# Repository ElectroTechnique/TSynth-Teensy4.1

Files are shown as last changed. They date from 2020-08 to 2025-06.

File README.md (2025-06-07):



# Teensy 4.1 based synthesizer using PJRC Audio Board and Audio Lib

Website: [electrotechnique.cc](https://electrotechnique.cc)

Front panel and Main PCB files are now available if you wan to get your own from a PCB facility like JLCPCB.

~~The pcb and front panel to build TSynth are available from [Tindie](https://www.tindie.com/products/electrotechnique/tsynth-teensy-based-diy-programmable-poly-synth/) with SMD 4067 multiplexers, 6N137 opto-isolator, capacitors and resistors fitted.~~ 

The entire cost of parts to build TSynth will be around $99 if you buy components from the cheaper suppliers and the build time around two hours to solder.
Plans for a 3D printed/laser cut enclosure are also available.

Questions: info@electrotechnique.cc

# Preset Patches
Format your SD card using [the SD Association formatter](https://www.sdcard.org/downloads/formatter/). Copy all the presets straight on to the card with no other files or folders.

# Instructions

The source code **requires** the latest Teensyduino from [PJRC](https://pjrc.com) to compile. You also need CircularBuffer from Agileware and Adafruit_GFX, which are available in the Arduino Library Manager.

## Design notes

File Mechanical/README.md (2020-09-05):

- Electrical schematic
- 3D models - End cheeks, side panel columns, display standoff, encoder knob (D-shape shaft)

    EncoderKnobEC12_6mm is for 6mm splined encoder shafts
    
    EncoderKnobEC12_D_shape is for 6mm D-shaped encoder shafts

- Laser cutter plans - Sides and base

    T4_1_LaserCutCase3_5Jk.svg - Is for PCBs with 3.5mm headphone sockets
  
    T4_1_LaserCutCase6_35Jk.svg - Is for PCBs with 1/4" / 6.35mm headphone sockets
  
- BOM Excel file for ordering from Mouser

Fusion 360 models. These have internal dimensions for slots that are slightly bigger, to account for shrinkage of PLA plastic:
- [End Cheeks](https://a360.co/3azEESA)
- [Side Panel Column](https://a360.co/34T8akU)

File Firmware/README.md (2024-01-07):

Get the firmware file from [RELEASES](https://github.com/ElectroTechnique/TSynth-Teensy4.1/releases) on the right-hand side of the main page.

Use [TyUploader](https://github.com/Koromix/tytools/releases/tag/v0.9.9) instead of TeensyDuino if you are tired of trying to press the Boot button on the T4.1

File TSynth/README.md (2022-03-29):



# Teensy 4.1 based synthesizer using PJRC Audio Board and Audio Lib

Website: [electrotechnique.cc](https://electrotechnique.cc)

The pcb and front panel to build TSynth are available from [Tindie](https://www.tindie.com/products/electrotechnique/tsynth-teensy-based-diy-programmable-poly-synth/) with SMD 4067 multiplexers, 6N137 opto-isolator, capacitors and resistors fitted. The entire cost of parts to build TSynth will be around $99 if you buy components from the cheaper suppliers and the build time around two hours to solder. Plans for a 3D printed/laser cut enclosure are also available.
Questions: info@electrotechnique.cc

# Preset Patches
Format your SD card using [the SD Association formatter](https://www.sdcard.org/downloads/formatter/). Copy all the presets straight on to the card with no other files or folders.

# Instructions

The source code **requires** at least Teensyduino 1.54 from [PJRC](https://pjrc.com) to compile. You also need CircularBuffer from Agileware and Adafruit_GFX, which are available in the Arduino Library Manager. **NOTE** if using Teensyduino 1.55, you'll need to [remove a line from TeensyThreads.cpp](https://forum.pjrc.com/threads/68192-Teensyduino-1-55-Released)

See this thread if you get an error concerning utils/debug.h:  [https://forum.pjrc.com/threads/68192-Teensyduino-1-55-Released?highlight=utils%2Fdebug.h}(https://forum.pjrc.com/threads/68192-Teensyduino-1-55-Released?highlight=utils%2Fdebug.h)

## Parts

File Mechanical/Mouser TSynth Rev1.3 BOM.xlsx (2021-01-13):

Mouser # | Mfr. # | Manufacturer | Description | Order Qty. | Datasheet URL | Quoted Part Number | Order Quantity | Order Price | Min\Mult Order Qty
474-DEV-16771 | DEV-16771 | SparkFun Electronics | Development Boards & Kits - ARM Teensy 4.1 | 1 |  | 474-DEV-16771 | 1 | $29.38 | 1\1
485-4384 | 485-4384 | SparkFun Electronics | Audio IC Development Tools Teensy Audio Adaptor Board Rev D | 1 |  | 485-4384 | 1 | $19.94 | 1\1
652-PTV09A-4025UB103 | PTV09A-4025U-B103 | Bourns | Potentiometers 10K LINEAR 20% | 33 | https://www.mouser.com/datasheet/2/54/ptv09-777818.pdf | 652-PTV09A-4025UB103 | 33 | $0.672 | 1\1
653-B3F-4055 | B3F-4055 | Omron | Tactile Switches 12x12mm Std Ht .3 High-force 260g | 7 | https://www.mouser.com/datasheet/2/307/en-b3f-13826.pdf | 653-B3F-4055 | 7 | $0.44 | 1\1
642-AKTS22K | AKTSC22K | Apem | Switch Bezels / Switch Caps ROUND BLACK CAP | 7 | https://www.mouser.com/catalog/additional/Apem_6420_RoHS_Certificate.pdf | 642-AKTS22K | 7 | $0.23 | 1\1
859-LTL-4251NLC | LTL-4251NLC | Lite-On | Standard LEDs - Through Hole Yellow | 4 | https://www.mouser.com/catalog/additional/Lite_On_5938_RoHS_Certificate.pdf | 859-LTL-4251NLC | 4 | $0.14 | 1\1
652-PEC11R-4215K-S24 | PEC11R-4215K-S0024 | Bourns | Encoders 15mm SHAFT w/SWITCH | 1 | https://www.mouser.com/datasheet/2/54/PEC11R-777457.pdf | 652-PEC11R-4215K-S24 | 1 | $1.63 | 1\1
530-SS-52100-001 | SS-52100-001 | Bel | USB Connectors USB 2.0 R Angle Recpt Type A solder | 1 | https://belfuse.com/resources/datasheets/stewartconnector/ds-stw-usb-2.0-and-3.0-connectors.pdf | 530-SS-52100-001 | 1 | $0.43 | 1\1
530-SS-52300-001 | SS-52300-001 | Bel | USB Connectors USB 2.0 RA Receptacle Type B | 1 | https://belfuse.com/resources/datasheets/stewartconnector/ds-stw-usb-2.0-type-b-connectors.pdf | 530-SS-52300-001 | 1 | $0.98 | 1\1
161-3507-E | 161-3507-E | Kobiconn | Phone Connectors PHONE 3.5MM STEREO | 1 | https://www.mouser.com/datasheet/2/209/KC-301159-1171664.pdf | 161-3507-E | 1 | $0.96 | 1\1
806-KCDX-5S-N | KCDX-5S-N | Kycon | Circular DIN Connectors 5P R/A PCB NON SHLD 10mm CIRC DIN RECPT | 2 | https://www.mouser.com/datasheet/2/222/KCDX-334811.pdf | 806-KCDX-5S-N | 2 | $0.86 | 1\1
568-NYS216G | NYS216G | REAN / Neutrik | Phone Connectors 1/4" STEREO JACK .322" GOLD REAN | 1 | http://www.rean-connectors.com/en/products/1/4-jacks/nys216g | 568-NYS216G | 1 | $0.98 | 1\1
855-R30-1002202 | R30-1002202 | Harwin | Standoffs & Spacers M3 x 22mm THREAD HEX BRASS 5mm A/F | 7 | https://kr.mouser.com/datasheet/2/181/R30-100-1220592.pdf | 855-R30-1002202 | 7 | $0.55 | 1\1
855-R30-3000802 | R30-3000802 | Harwin | Standoffs & Spacers M3 x 8mm HEX 5mm A/F 6mm ML/FML NICKEL | 7 | https://kr.mouser.com/datasheet/2/181/R30-300-1136135.pdf | 855-R30-3000802 | 7 | $0.58 | 1\1
5164-1227-L | 1227-L | Davies Molding | Knobs & Dials S/T Control Knob 6mm Interference Fit | 34 | https://kr.mouser.com/datasheet/2/102/1227-L-1287203.pdf | 5164-1227-L | 34 | $0.91 | 1\1

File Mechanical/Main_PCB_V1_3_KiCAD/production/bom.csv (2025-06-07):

Designator | Footprint | Quantity | Value | LCSC Part #
C1, C10, C11, C12, C13, C14, C15, C16, C17, C18, C19, C2, C20, C21, C22, C23, C24, C25, C26, C27, C28, C29, C3, C30, C31, C32, C33, C34, C35, C36, C37, C4, C5, C6, C7, C8, C9 | 0805 | 37 | 0.1uF
D1 | LED_D3.0mm | 1 | Osc FX LED
D2 | LED_D3.0mm | 1 | Unison LED
D3 | LED_D3.0mm | 1 | Tempo LED
D4 | LED_D3.0mm | 1 | Retrig LED
D5 | D_SOD-323F | 1 | 1N4148WS
ENC1 | RotaryEncoder_Alps_EC11E-Switch_Vertical_H20mm | 1 | Recall
G1, G2 | TSynth PCB Logo 41mm | 2 | Logo
J1 | Jack_3.5mm_Ledino_KB3SPRS_Horizontal | 1 | 3.5mm Jack
J2 | PinHeader_1x03_P2.54mm_Vertical | 1 | To Audio Board
J3 | USB_A_Stewart_SS-52100-001_Horizontal | 1 | USB Host
J4 | USB_B_OST_USB-B1HSxx_Horizontal | 1 | USB Client
J5 | Jack_6.35mm_Neutrik_NMJ6HFD2_Horizontal | 1 | 1/4" Jack
J6 | PinHeader_1x08_P2.54mm_Vertical | 1 | SPI Display
J7 | MIDI_DIN5 | 1 | MIDI In
J8 | MIDI_DIN5 | 1 | MIDI Out/Thru
R10 | 0805 | 1 | 10R
R11 | 0805 | 1 | 33R
R12 | 0805 | 1 | 100R
R3, R4, R6, R8 | 0805 | 4 | 1k5
R7 | 0805 | 1 | 220R
R9 | 0805 | 1 | 4k7
RV1 | Potentiometer_Bourns_PTV09A-1_Single_Vertical | 1 | Noise
RV10 | Potentiometer_Bourns_PTV09A-1_Single_Vertical | 1 | PWM Rate
RV11 | Potentiometer_Bourns_PTV09A-1_Single_Vertical | 1 | Osc2 Pitch
RV12 | Potentiometer_Bourns_PTV09A-1_Single_Vertical | 1 | Osc2 Waveform
RV13 | Potentiometer_Bourns_PTV09A-1_Single_Vertical | 1 | Osc2 PWM Amt
RV14 | Potentiometer_Bourns_PTV09A-1_Single_Vertical | 1 | Osc1 Pitch
RV15 | Potentiometer_Bourns_PTV09A-1_Single_Vertical | 1 | Osc1 Waveform
RV16 | Potentiometer_Bourns_PTV09A-1_Single_Vertical | 1 | Osc1 PWM Amt
RV17 | Potentiometer_Bourns_PTV09A-1_Single_Vertical | 1 | Release Amp
RV18 | Potentiometer_Bourns_PTV09A-1_Single_Vertical | 1 | Sustain Amp
RV19 | Potentiometer_Bourns_PTV09A-1_Single_Vertical | 1 | Decay Amp
RV2 | Potentiometer_Bourns_PTV09A-1_Single_Vertical | 1 | Pitch LFO Rate
RV20 | Potentiometer_Bourns_PTV09A-1_Single_Vertical | 1 | Attack Amp
RV21 | Potentiometer_Bourns_PTV09A-1_Single_Vertical | 1 | Filter LFO Amt
RV22 | Potentiometer_Bourns_PTV09A-1_Single_Vertical | 1 | FX Mix
RV23 | Potentiometer_Bourns_PTV09A-1_Single_Vertical | 1 | FX Amt
RV24 | Potentiometer_Bourns_PTV09A-1_Single_Vertical | 1 | Glide
RV25 | Potentiometer_Bourns_PTV09A-1_Single_Vertical | 1 | Filter LFO Wave
RV26 | Potentiometer_Bourns_PTV09A-1_Single_Vertical | 1 | Filter LFO Rate
RV27 | Potentiometer_Bourns_PTV09A-1_Single_Vertical | 1 | Cutoff
RV28 | Potentiometer_Bourns_PTV09A-1_Single_Vertical | 1 | Resonance
RV29 | Potentiometer_Bourns_PTV09A-1_Single_Vertical | 1 | Filter Type
RV3 | Potentiometer_Bourns_PTV09A-1_Single_Vertical | 1 | Pitch LFO Wave
RV30 | Potentiometer_Bourns_PTV09A-1_Single_Vertical | 1 | Sustain Filter
RV31 | Potentiometer_Bourns_PTV09A-1_Single_Vertical | 1 | Release Filter
RV32 | Potentiometer_Bourns_PTV09A-1_Single_Vertical | 1 | Filter Env Amt
RV33 | Potentiometer_Bourns_PTV09A-1_Single_Vertical | 1 | Volume
RV4 | Potentiometer_Bourns_PTV09A-1_Single_Vertical | 1 | Pitch LFO Amt
RV5 | Potentiometer_Bourns_PTV09A-1_Single_Vertical | 1 | Detune
RV6 | Potentiometer_Bourns_PTV09A-1_Single_Vertical | 1 | Osc Mix
RV7 | Potentiometer_Bourns_PTV09A-1_Single_Vertical | 1 | Attack Filter
RV8 | Potentiometer_Bourns_PTV09A-1_Single_Vertical | 1 | Decay Filter
RV9 | Potentiometer_Bourns_PTV09A-1_Single_Vertical | 1 | Pitch Env Mod
SW1 | SW_PUSH-12mm | 1 | Osc FX
SW2 | SW_PUSH-12mm | 1 | Unison
SW3 | SW_PUSH-12mm | 1 | Tempo
SW4 | SW_PUSH-12mm | 1 | Retrig
SW5 | SW_PUSH-12mm | 1 | Settings
SW6 | SW_PUSH-12mm | 1 | Save
SW7 | SW_PUSH-12mm | 1 | Back
U1 | Teensy41 | 1 | Teensy4.1
U2, U3 | SOIC-24W_7.5x15.4mm_P1.27mm | 2 | CD74HC4067M
U4 | SMDIP-8_W9.53mm | 1 | 6N137
U5 | SOIC-14_3.9x8.7mm_P1.27mm | 1 | 74HC04

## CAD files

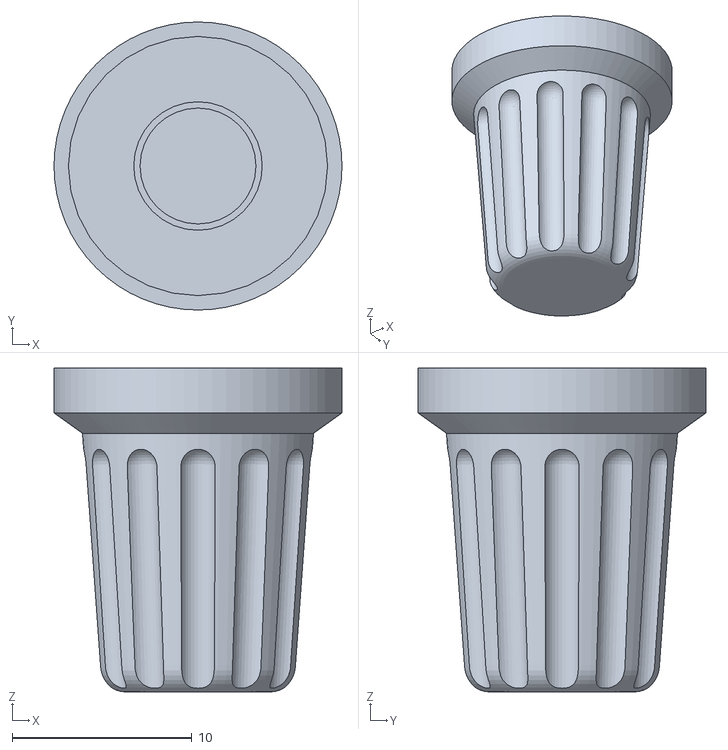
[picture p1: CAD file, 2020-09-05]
Mechanical/EncoderKnobEC12_6mm.stl
16.0 x 16.0 x 18.0

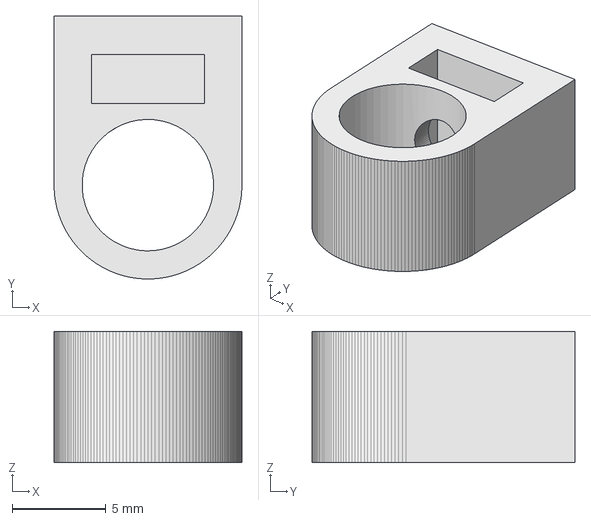
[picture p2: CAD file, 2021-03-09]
Variants/Mechanical/SidePanel_Column_LargerHole.FCStd
10.0 x 14.0 x 7.00 mm

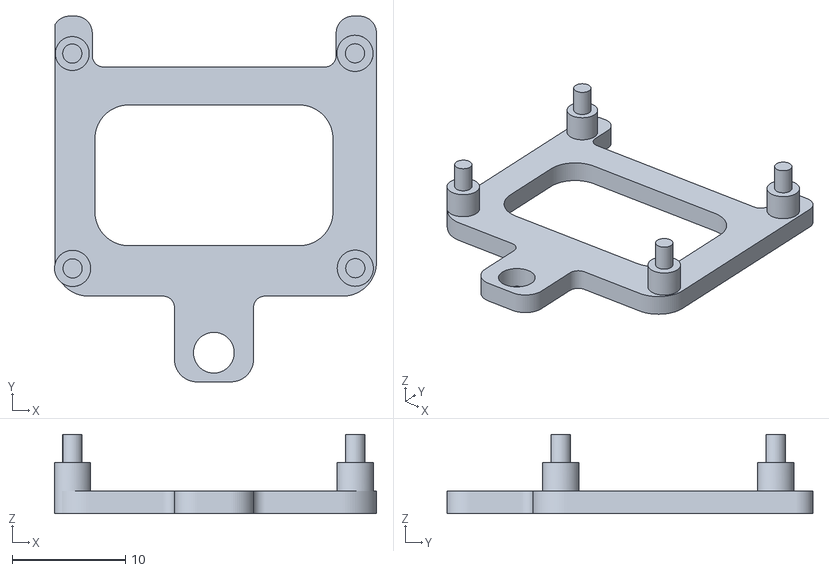
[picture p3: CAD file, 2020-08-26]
Mechanical/0_96_Display_Standoff.stl
28.5 x 32.3 x 7.00

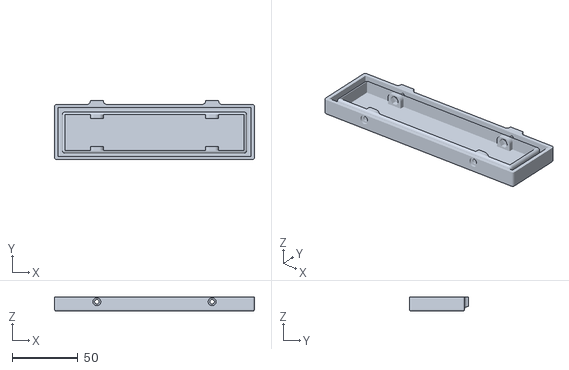
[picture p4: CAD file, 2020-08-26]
Mechanical/EndCheek.stl
152.5 x 45.1 x 11.0

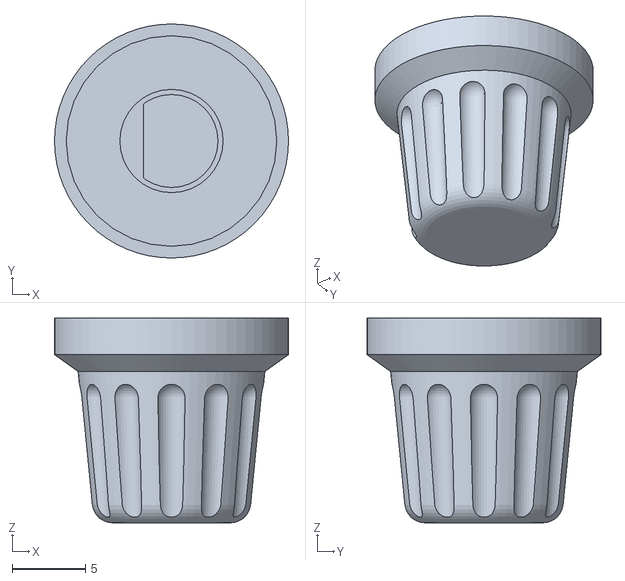
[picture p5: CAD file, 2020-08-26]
Mechanical/EncoderKnobEC12_D_shape.stl
16.0 x 16.0 x 14.0

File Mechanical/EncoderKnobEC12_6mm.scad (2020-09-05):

module pill(_height, _radius){
union() {
translate([0,0,0]) sphere(r=_radius, $fn=32);
translate([0,0,0]) cylinder(r=_radius,h=_height, $fn=32);
translate([0,0,_height]) sphere(r=_radius, $fn=32);
}
}


module base1(_base_height,_base_radius,_knob_radius) {
union() {
cylinder(r=_base_radius, h=_base_height, $fn=64);
translate([0,0,_base_height]) cylinder(r1=_base_radius, r2=_knob_radius, h=5, $fn=64);
}
}
module base2(_base_height,_base_radius,_ring_radius) {
union() {
cylinder(r1=_base_radius+1, r2=_base_radius, h=_base_height, $fn=64);
translate([0,0,_base_height]) rotate_extrude(convexity = 10, $fn=64)
translate([_base_radius-_ring_radius, 0, 0])
circle(r = _ring_radius, $fn=32);
translate([0,0,_base_height]) cylinder(r=_base_radius-_ring_radius, h=_ring_radius, $fn=64);
}
}

base_height=2.5;
base_radius=8;

knob_height=14;//16
knob_radius=5.5;

shaft_radius=3.22;//3.18;//3.1
nut_radius=7.2;
nut_height=2.7;
shaft_height=8.8;//16
shaft_height_total=13;//18


rotate([0,180,0]) {
    difference(){
union(){
base1(base_height, base_radius, 1);

translate([0,0,base_height]) {
difference() {
base2(knob_height, knob_radius, 1.5);
for (i=[0:30:360]) {
   rotate([0,0,i]) translate([knob_radius+1,0,3]) rotate([0,-3.5,0]) pill(knob_height+1, 1);
}
}
}
}
union() {
cylinder(r=nut_radius, h=nut_height,$fn=32);
difference() {
    union() {
cylinder(r=shaft_radius, h=shaft_height_total,$fn=32);

cylinder(r=shaft_radius+0.35, h=shaft_height_total-shaft_height,$fn=32);
    }
//#translate([1.9,-shaft_radius,shaft_height_total-shaft_height]) //cube([2*shaft_radius,2*shaft_radius,shaft_height]);
}
}
}

}

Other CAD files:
Mechanical/Side_Panel_Column.stl
Mechanical/EncoderKnobEC12_D_shape.scad
Variants/Mechanical/SidePanel_Column_LargerHole.stl

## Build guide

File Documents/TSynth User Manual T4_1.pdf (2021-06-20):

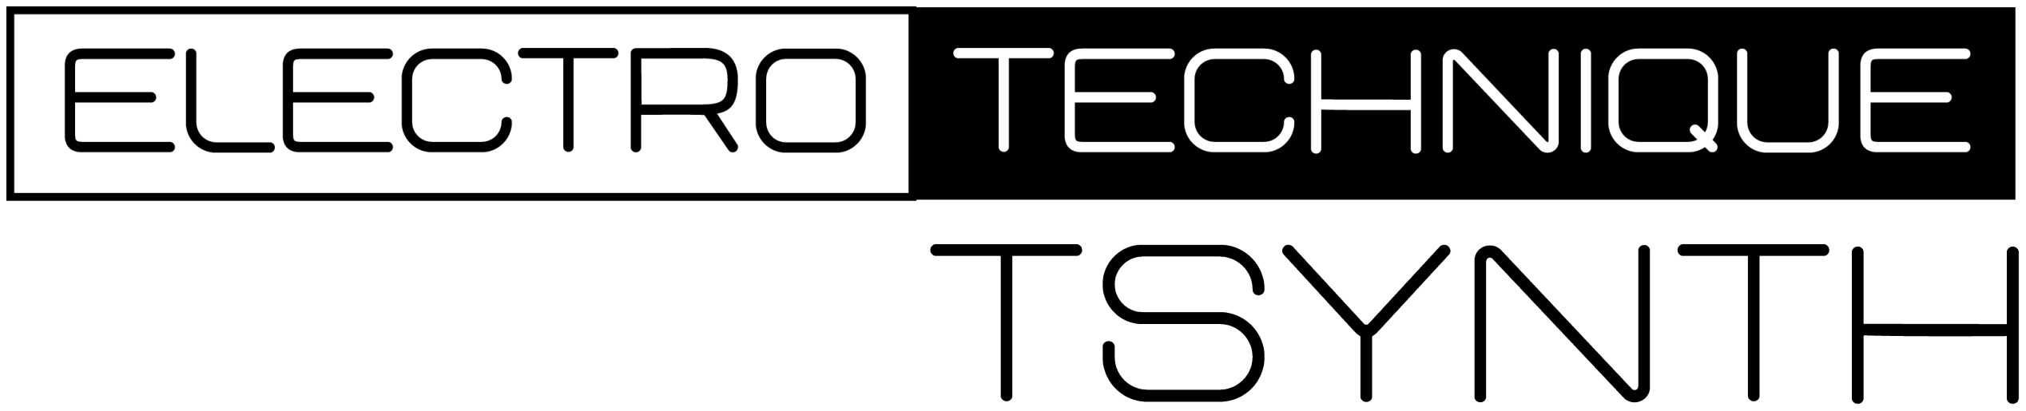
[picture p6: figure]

# User Manual

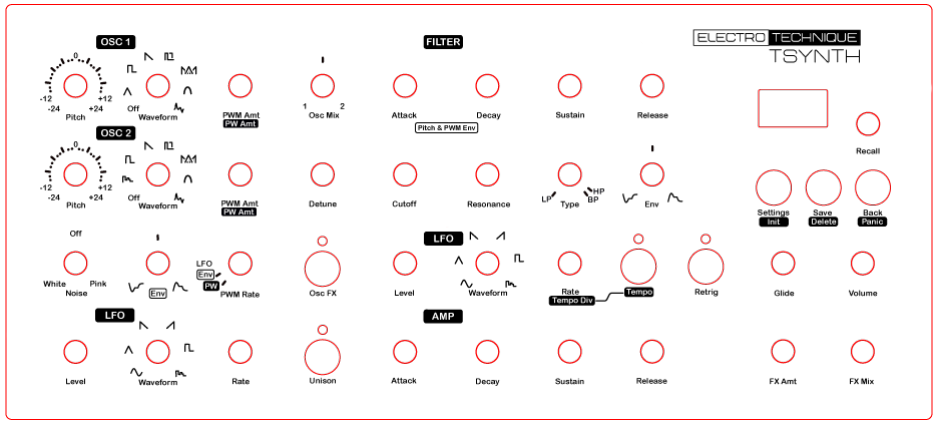
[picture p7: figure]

TSynth is a 12 voice programmable polyphonic synthesizer based on the Teensy 4.1 microcontroller board. The front panel is divided into distinct regions that should be familiar to anyone who has used an analogue or analogue-like synthesizer.

### Oscillators

Both oscillators are identical except for the first and last waveforms. Oscillator 1 has triangle and oscillator 2 has sample & hold (which is an audible random value pulse wave.) Octave sets the pitch of the oscillator relative to the other. It ranges from -24 semitone to +24 semitones with values of -24 and -12 to +12 in semitone intervals, then +24. The waveforms available are the usual triangle, square, sawtooth, the already mentioned sample & hold, plus variable pulse, variable triangle (sawtooth to triangle to ramp waveforms), rectified sine (parabola) and harmonic (these differ on both oscillators for variety).
Pulse width may be set to a fixed value or modulated using the filter envelope or a dedicated LFO - PWM Rate (see section on PWM Controls.)
The volumes of each oscillator may be adjusted using Osc Mix, which mixes between both oscillators on full (middle) or decreasing one down to zero while the other is full. To turn an oscillator off, the waveform can be set to Off.
Detune detunes oscillator 2 relative to oscillator 1 and is useful for giving a thicker, chorus-like effect. This also works with Unison, which will detune all the voices relative to the others, up to the maximum set by Detune.
Noise will allow White or Pink noise to be introduced. The centre setting is Off and adjusting each side will increase the volume of either White or Pink.

Teensy 4.1
Firmware 2.30 & higher
May 2021

Env is a pitch modulation applied by the filter envelope. Centre setting is none and this may be adjusted to increase a negative or postive envelope. Negative (anticlockwise) goes down then up. Positive (clockwise) goes up then down.
The oscillators have their own dedicated LFO. This has a Level control for the amount. A Waveform choice and a Rate (speed) setting. The Waveforms are sine, triangle, sawtooth, ramp (or reverse sawtooth), square and sample & hold.
Osc FX applies a choice of two effects to the oscillators. Keep pressing to cycle through:
- A Korg MS20 style, XOR type ‘ring modulation’ effect. This introduces harmonics to the sound and may not work well with certain combinations of waveforms such as two pulse types.
- Cross Modulation (X Mod) modulates one oscillator with the other, depending on the postion of the Osc Mix control. Turning past the centre to the left increase modulation of oscillator 1 by oscillator 2. Turning towards the right increases modulation of oscillator 2 by 1.
Unison has two types. Keep pressing to cycle through:
- Dynamic Unison sounds all the oscillators together when up to four notes are played. This is dynamic and will divide up the 24 oscillators between one, two, three or four notes. As mentioned, Detune will set all the oscillators slightly detuned from each other up to the maximum set by the Detune control.
- Chord Unison will play all 24 oscillators on one note, divided up into pitches corresponding to the notes in various chords. The Detune control will set the chord type (major, minor, augmented...)

### PWM Controls

Both oscillators feature variable pulse and variable triangle waveforms that can be manually adjusted or modulated by the filter envelope or a dedicated LFO.
Fixed Pulse Width / Triangle shape
Set the PWM Rate control to zero where it’s marked PW. The two controls above - PW Amt will set the pulse width / triangle shape. The central middle setting corresponds to a square wave (50% duty cycle) or a triangle waveform depending on the oscillator waveform.
Pulse Width / Triangle shape modulation by filter envelope
Set the PWM Rate control to where it’s marked Env. The two controls above - PWM Amt will set the amount of modulation pulse width / triangle shape receive from the filter envelope.
Pulse Width / Triangle shape modulation by LFO
Set the PWM Rate control to LFO and above. The two controls above - PWM Amt will set the amount of modulation the pulse width / triangle shape receive from the a dedicated LFO. PWM Rate will adjust the rate (speed) of this LFO. The LFO waveform is a sine wave.

### Filter

The Filter section features an ADSR envelope with Attack, Decay and Release times from 1ms up to almost 12s, which is also used by the oscillators pitch envelope and by the PWM control, as outlined in the Oscillators section. The time of the Release stage is the time taken to reach about -8dB. This is due to its exponential shape. The envelope modulates the cutoff frequency of the filter and the amount of the effect is by the Env control, which allows a positive (clockwise) or negative (anticlockwise) modulation of the cutoff.
The cutoff frequency is controlled by the Cutoff control, with resonance level set by the Resonance control. The Type control will vary the filter type between low pass (LP) through to high pass (HP)

acting as a notch filter, to band pass (BP). This is known as a state variable filter and has a 12dB per octave cutoff response. Resonance may produce distortion when set to full with the cutoff at the resonant frequencies of particular waveforms.
There is a dedicated LFO for the filter with a Level control, a selection of Waveforms and a Rate (speed) control. Setting the Tempo switch to on, makes the LFO sync with incoming MIDI clock signals (24ppqn) from a sequencer (like Ableton Live, Logic Pro etc) This also allows the Rate control to set the tempo divisions for a particular tempo. The Tempo Div control will allow the LFO to sync to a frequency that is a division of a bar 1/16, 3/32, 1/8, 3/16, 1/4 .... for a particular tempo, in beats per minute (bpm). Retrig will retrigger the LFO to start from the same point in the waveform every time a new note is pressed regardless of whether other notes are still held. This can be useful if you want to play a series of notes and have the filter modulate each note in the same way.

### Amplifier

This is a standard ADSR envelope with Attack, Decay and Release times from 1ms up to almost 12s. The time of the Release stage is the time taken to reach about -8dB. This is due to its exponential shape. Velocity sensitivity is set in the Settings menu.

### Recalling Patches

Turning the Recall encoder next to the display will move through each saved patch and sets it to be current. Pressing the encoder brings up a list of the saved patches that can be moved through. Pressing the encoder then sets the highlighed one as the current. Back button will cancel.
If a patch has been modified, pressing the encoder sets it back to how it was saved.

### Saving and Naming Patches

Back button will cancel and move back to previous screen. If you make a mistake naming patches, press back button.

### Save a new patch

Save Recall Turn the Recall encoder to select
letters and numbers. Press Recall to select each character and move to the next one to select. Press to select final character.
- Save

### Overwriting an existing patch

Save Turn the Recall encoder to select the patch to overwrite.

- Save

### Renaming an existing patch

Save Turn the Recall
encoder to select the patch
to rename and
press Recall.
- Turn the Recall encoder to select letters and numbers. Press Recall to select each character and move to the
next one to select. Press to select final character.
- Save

### Settings

Pressing Settings allows access to a number of patch and global level settings for TSynth. These are:
MIDI Ch. - The MIDI channel TSynth will accept incoming MIDI data on, including All (Omni on). This is global.
Key Tracking - This modulates the filter cutoff frequency as you go up the keyboard to higher notes. The idea is that the cutoff increases to allow higher frequencies to sound clearer. It can be set to None (cutoff doesn’t change) Half (some effect) and Full (full effect). This is saved with the patch.
Velocity Sens - This sets the velocity sensitivity of the amplifier and has four curves:
1 - Linear, velocity value corresponds directly to the loudness. 2 - Curve to maximum loudness.
3 - Curve to maximum loudness at 70 and then flatten.
4 - Curve up to maximum loudness.

Choose an appropriate curve for the keyboard response. This is saved with the patch. Monophonic - this sets monophonic mode, with Last, First, Highest and Lowest priority. This is saved with the patch.
Pitch Bend - this sets the pitch bend range in semitones. This is global.
MW Depth - this sets the modulation wheel maximum depth. This is like the level control in the oscillator LFO section but allows lower levels of modulation (vibrato in this case) to be applied. This is global.
MIDI Out Ch. - The channel MIDI out will transmit on. Can be switched off. Only works over USB host and client and is useful for recording parameter changes while recording a sequence. This is global.
MIDI Thru - (This is for V1.3+ PCBs) The MIDI Out/Thru DIN socket can be set to either output MIDI CC values from the controls (see MIDI Out Ch.) or function as a MIDI Thru. OFF switches it off and the socket works as MIDI OUT. Full allows all MIDI In data thru. Same Ch. filters data so that only data on the current MIDI In channel passes thru. Diff. Ch. filters MIDI In data so that data on a different channel to the current one passes thru. This is global.

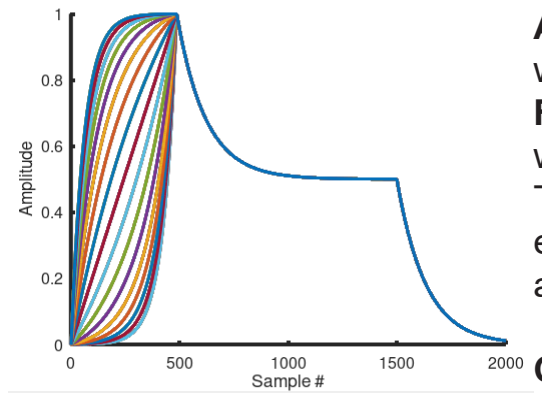
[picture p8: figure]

Amp Env - this sets the attack shape of the amplifer envelope with a shape below. This is global.
Filter Env - this sets the attack shape of the filter envelope with a shape below. This is global.
The atttack stage on the envelope can be set to be linear and exponential with -8 being a flattening curve at the maximum and +8 being an increasing rise.
Glide Shape - Choose linear or exponential (slows toward end) response. This is global.

Encoder - Choose Type 1 or Type 2 depending on how your encoder produces pulses when turning. If your encoder decrements when turning clockwise, change the type here. This is global.
Pick-up - An experimental feature that only allows a panel control and the corresponding MIDI CC control, to start changing the parameter value when it matches the current patch value. This is to prevent jumps when the control suddenly changes the parameter value. Turn the control slowly and smoothly, and the control will pick-up the current value when it gets to it and change it. An icon of a knob appears on the display when changing parameters, when this is on. This is global.
Bass Enh. - This enhances the bass frequencies using the SGTL5000 codec chip on the audio board and doesn’t involve the Teensy. This will only affect audio from the headphone socket. This is global. Oscilloscope - An experimental feature that shows what the waveforms look like. This is taken just before the stereo chorus effect. This is global.
VU Meter - This is a linear meter that shows the amplitude of the audio signal - not really VU standard. This is global.
The Settings menu allows scope for expansion; for example, velocity sensitivity could be set for the modulation of the filter cutoff frequency. You could set different types of filter, user waveforms, effects...

### Initialisation

Pressing and holding the Settings button for one second invokes Init, which will re-read all the panel controls and set TSynth to the current panel settings.

### Other Specifications

Power - 5V 180mA from USB. TSynth can run from a 4000mAh powerbank for a day.
Digital Audio - 16 bit, 44.1Hz - headphone jack and audio interface recommended for recording.

### Known Issues

Plugging in a MIDI controller may alter current patch settings. Arturia Minilab for example, sends its current panel control settings when plugged in, causing MIDI CC messages to be received by TSynth, altering settings.
Low cost (sub $10) USB to MIDI converters can have problems handling clock signals and SysEx, which get mixed up with note on/off and CC messages. Use quality converters made by a known brand name. There is a significant latency (delay) between TSynth receiving a MIDI note and hearing it on a computer via USB audio - about 100ms. For recording, use the headphone output and send through a quality audio interface featuring low latency ASIO drivers.

### Troubleshooting

No sound
- Check Waveforms are not set to off and volume is mid way.
- Check filter cutoff and filter type will allow sound through.
- Pulse Width of Pulse waveforms will be quiet if set to maximum (very narrow!)
- If using digital audio via USB, check your computer. Windows sometimes doesn’t pass the audio through - Go into the Control Panel, Manage Audio Devices and the Recording tab. Double-click the digital audio device and go into the Listen tab and set the Listen to this device to on - you may find it’s already on and you have to toggle it off and on so it works again.
Pressing Init to set TSynth to the panel control current settings and with the controls set to make sound, will show if there is a problem.

Digital noises
This may happen occasionally when using the USB digital audio. The analogue audio is fine.

Humming Noises
This could be attributable to ground or mains noise through the USB port if connected to a pc or an external amplifier and needs action by you see what configuration works. TSynth can be powered from a USB powerbank and played by a small MIDI controller without an attachment to the mains or a pc, this would show if noise is from the mains or possibly your computer.

SD Card problems
Use a low value (1GB is more than enough!) SD card. It doesn’t need to be particularly fast and cheaper, older cards are fine. Ensure that the card is formatted as FAT16/32 before using it and the SDFormatter application from the SD Association is recommended: www.sdcard.org/downloads/formatter/ Other problems
If there are intermittant problems, check the hardware. Are there dry solder joints? Is the Teensy properly seated in the header socket if you used one? Are the potentiometers smooth? Did you solder the wires to the USB pads on the Teensy properly? Did you solder the wires from the Audio Board to the audio pads on the PCB properly? TSynth is a DIY project and it is up to the individual to build it properly.

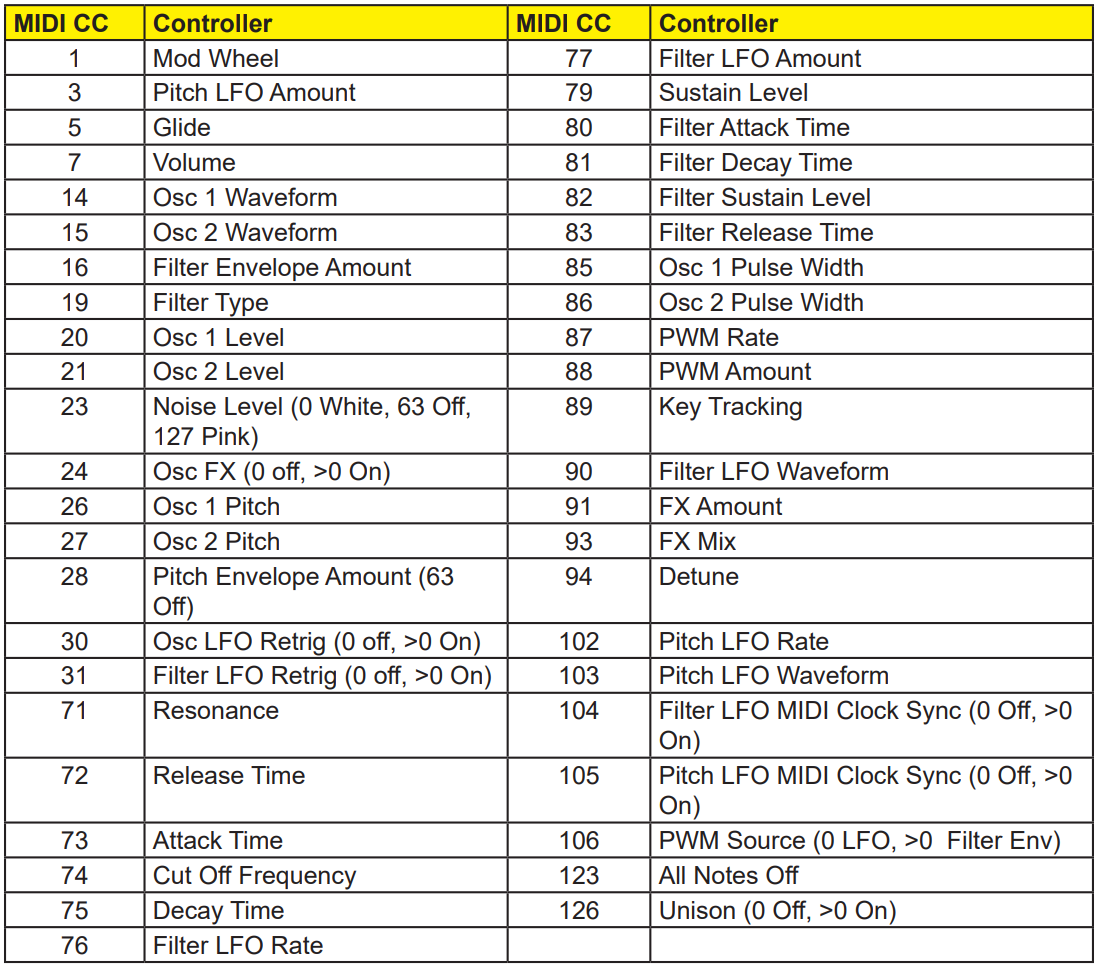
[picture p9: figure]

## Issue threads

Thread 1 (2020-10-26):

Potentiometers

callimero, 2020-10-26:
Information about the potis is quite cluttered. Maybe just put in the exact Type(s)?

Splined ALPS RVXX seems to be have a "K" (KNOB) in the end i.e RVXXK for splined axle

The  "15mm long shaft" is not a measurement in the most drawings. Do you mean "L" (LM1 in ALPS drawings)? Or the part of the splined Axle? Or really the lenght of the axle without the housing?

callimero, 2020-10-27:
Found the BOM, however there are more people wishing the build guide would be more accurate.

Closed 2020-10-27.

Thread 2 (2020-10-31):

Remembering last Patch used

callimero, 2020-10-31:
I tink it would be a good idea to start with the last patch used (at least for me)

I hacked(!) this and it somehow works :) No cleanup and this language is way out of my comfort zone...

https://github.com/ElectroTechnique/TSynth-Teensy4.1/compare/master...callimero:Carsten

Things:
- After start the last patch is showed and works, however the list is not updated, so turning the Encoder switches to 1 or 3 I think
- Massive writing to EEprom should be avoided right? So there needs to be a mechanism to detect if the patch is not changed some time and only then write to eeprom, so scrollng through the list is not writing constantly to eeprom
- Should there be a Setting to enable this functionality

callimero, 2020-11-04:
I added a setting to it so it can be used or not.

Still no idea why or how the list needs to be regenerated, so after loading an old patch turning the Encoder Patch jumps to first or last patch

callimero, 2020-11-04:
setPatchesOrdering(patchNo); did not hide good enough! :) Works now. I guess its not pretty but...

callimero, 2020-11-16:
Sorry I am a github noob, I should have done branches for every feature.

Closed 2021-07-26.

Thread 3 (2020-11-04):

Sustain Pedal support

callimero, 2020-11-04:
There is a Midi cc# 64 which is mostly used for sustain pedals.

I was able to hack that in. However as I am not digged deep into the code I just made a proof that I am more a hacker than a developer. I just setting release to the decay value when the pedal is pressed. And restore it when released. This works for the piano type sound (well Rhodes) besides that I did not manage to stop the releasing when the pedal is left off (allNotesOff(); seems not to do it) so I use closeEnvelopes(); but that just cuts (ok for me here).

Of course a Hold should put the envelopes into the Decay phase I guess. I only can imagine that this could be done by not sending NoteOff()s but I did not found a way to do it right now.

The other thing in this context is that maybe a hardware port for a sustain pedal should be supported? I think this is a nice thing to have for a 12 voices synth.

callimero, 2020-11-04:
Erm... could it be that simple? Sounds fine to me.

`
void myNoteOff(byte channel, byte note, byte velocity) {
if (ampHold==0)
{
  decNotesOn();
  if (unison == 0) {
    endVoice(getVoiceNo(note));
  } else {
    //UNISON MODE
    for (int i = 0; i < NO_OF_VOICES; i++) {
      endVoice(getVoiceNo(note));
    }
  }
  }
}
`

`    case CChold:
	 if (value>0)
		{
			ampHold = ampRelease;
		}
		else
		{
			ampHold=0;
		allNotesOff();
		}
		break;
`

callimero, 2020-11-04:
There is also another way, which could be a setting (I am just keep saying here, I have no clue if this is all doable)

`
MIDI CC 66 | Sostenuto On/Off Switch | On/Off switch – Like the Sustain controller (CC  64), However it only holds notes that were “On” when the pedal was  pressed. People use it to “hold” chords” and play melodies over the held  chord.
`

callimero, 2020-11-16:
Sorry I am a github noob, I should have done branches for every feature.

Closed 2021-05-15.

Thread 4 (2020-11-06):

Typo in voice1On? Re-Read please

callimero, 2020-11-06:
In voic1One there is

voiceMixer1.gain(0, VELOCITY[velocitySens][velocity] * level);

In all other voices it is:

voiceMixer1.gain(1, VELOCITY[velocitySens][velocity] * VOICEMIXERLEVEL);

`
void voice1On(byte note, byte velocity, float level) {
  keytracking1.amplitude(note * DIV127 * keytrackingAmount);
  voices[0].note = note;
  voices[0].timeOn = millis();
  **voiceMixer1.gain(0, VELOCITY[velocitySens][velocity] * level);**
  filterEnvelope1.noteOn();
  ampEnvelope1.noteOn();
  voices[0].voiceOn = 1;
  if (glideSpeed > 0 && note != prevNote) {
    glide1.amplitude((prevNote - note) * DIV24);   //Set glide to previous note frequency (limited to 1 octave max)
    glide1.amplitude(0, glideSpeed * GLIDEFACTOR); //Glide to current note
  }
  if (unison == 0)prevNote = note;
}

void voice2On(byte note, byte velocity, float level) {
  keytracking2.amplitude(note * DIV127 * keytrackingAmount);
  voices[1].note = note;
  voices[1].timeOn = millis();
  **voiceMixer1.gain(1, VELOCITY[velocitySens][velocity] * VOICEMIXERLEVEL);**
  filterEnvelope2.noteOn();
  ampEnvelope2.noteOn();
  voices[1].voiceOn = 1;
  if (glideSpeed > 0 && note != prevNote) {
    glide2.amplitude((prevNote - note) * DIV24);   //Set glide to previous note frequency (limited to 1 octave max)
    glide2.amplitude(0, glideSpeed * GLIDEFACTOR); //Glide to current note
  }
  if (unison == 0)prevNote = note;
}

`

ElectroTechnique, 2020-11-14:
Untrue, each voice has it's own mixer input on the the three mixers.

callimero, 2020-11-14:
Maybe I did not communicate very good:

On Voice one it is

voiceMixer1.gain(0, VELOCITY[velocitySens][velocity] * **level**);

On **all** other voices it is

voiceMixer1.gain(1, VELOCITY[velocitySens][velocity] * **VOICEMIXERLEVEL**);

So Voice 1 uses the level parameter, all others using the Constant VOICEMIXERLEVEL

Thats something I don't get.

ElectroTechnique, 2020-11-15:
Fixed in V2.02

Closed 2020-11-15.

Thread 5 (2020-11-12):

Error compiling for board Teensy 4.1

dwestbury, 2020-11-12:
Can't seem to get the Teensyduino sketch to compile?

IDE Tools Settings: (all confirmed)
    Board: "Teensy4.1"
    USB Type: "Serial + MIDI + Audio"
    CPU Speed: "600MHz"
    Optimize: "Faster"

Am I using all the right library versions?

`
collect2: error: ld returned 1 exit status

Using library Audio at version 1.3...
Using library SPI at version 1.0...
Using library Adafruit_GFX_Library at version 1.10.2...
Using library Wire at version 1.0...
Using library SD at version 1.2.2...
Using library MIDI at version 5.0.2...
Using library USBHost_t36 at version 0.1...
Using library TeensyThreads at version 1.0.1...
Using library CircularBuffer at version 1.3.3...
Using library Encoder at version 1.4.1...
Using library Bounce...
Using library ADC at version 8.0...
Using library EEPROM at version 2.0...
Using library SerialFlash at version 0.5...
Using library Adafruit_BusIO at version 1.6.0...

Error compiling for board Teensy 4.1.
`

callimero, 2020-11-12:
Maybe not. :/ Which Arduino IDE are you using? Teensy audio has also some requirements, I installed 1.8.13 for TSynth.

Then check if you have the said libs installed (here in git in README).

For me it was I think a problem with the Circular buffer versions.

callimero, 2020-11-12:
Here is mine which compiles fine.
`
C:\Desktop_Ext\arduino-1.8.13\arduino-builder -dump-prefs -logger=machine -hardware C:\Desktop_Ext\arduino-1.8.13\hardware -hardware C:\Users\cw.Mero\AppData\Local\Arduino15\packages -hardware C:\Users\cw.Mero\Documents\Arduino\hardware -tools C:\Desktop_Ext\arduino-1.8.13\tools-builder -tools C:\Desktop_Ext\arduino-1.8.13\hardware\tools\avr -tools C:\Users\cw.Mero\AppData\Local\Arduino15\packages -built-in-libraries C:\Desktop_Ext\arduino-1.8.13\libraries -libraries C:\Users\cw.Mero\Documents\Arduino\libraries -fqbn=teensy:avr:teensy41:usb=serialmidiaudio,speed=600,opt=o2std,keys=en-us -ide-version=10813 -build-path C:\Users\CW7930~1.MER\AppData\Local\Temp\arduino_build_933994 -warnings=none -build-cache C:\Users\CW7930~1.MER\AppData\Local\Temp\arduino_cache_436801 -verbose C:\Users\cw.Mero\Documents\Makes\TSynth\TSynth-Teensy4.1\TSynth\TSynth.ino
C:\Desktop_Ext\arduino-1.8.13\arduino-builder -compile -logger=machine -hardware C:\Desktop_Ext\arduino-1.8.13\hardware -hardware C:\Users\cw.Mero\AppData\Local\Arduino15\packages -hardware C:\Users\cw.Mero\Documents\Arduino\hardware -tools C:\Desktop_Ext\arduino-1.8.13\tools-builder -tools C:\Desktop_Ext\arduino-1.8.13\hardware\tools\avr -tools C:\Users\cw.Mero\AppData\Local\Arduino15\packages -built-in-libraries C:\Desktop_Ext\arduino-1.8.13\libraries -libraries C:\Users\cw.Mero\Documents\Arduino\libraries -fqbn=teensy:avr:teensy41:usb=serialmidiaudio,speed=600,opt=o2std,keys=en-us -ide-version=10813 -build-path C:\Users\CW7930~1.MER\AppData\Local\Temp\arduino_build_933994 -warnings=none -build-cache C:\Users\CW7930~1.MER\AppData\Local\Temp\arduino_cache_436801 -verbose C:\Users\cw.Mero\Documents\Makes\TSynth\TSynth-Teensy4.1\TSynth\TSynth.ino
Using board 'teensy41' from platform in folder: C:\Desktop_Ext\arduino-1.8.13\hardware\teensy\avr
Using core 'teensy4' from platform in folder: C:\Desktop_Ext\arduino-1.8.13\hardware\teensy\avr
Detecting libraries used...
...
Opening Teensy Loader...
Mehrere Bibliotheken wurden für "SD.h" gefunden
 Benutzt: C:\Desktop_Ext\arduino-1.8.13\hardware\teensy\avr\libraries\SD
 Nicht benutzt: C:\Desktop_Ext\arduino-1.8.13\libraries\SD
Bibliothek Audio in Version 1.3 im Ordner: C:\Desktop_Ext\arduino-1.8.13\hardware\teensy\avr\libraries\Audio  wird verwendet
Bibliothek SPI in Version 1.0 im Ordner: C:\Desktop_Ext\arduino-1.8.13\hardware\teensy\avr\libraries\SPI  wird verwendet
Bibliothek Adafruit_GFX_Library in Version 1.6.1 im Ordner: C:\Users\cw.Mero\Documents\Arduino\libraries\Adafruit_GFX_Library  wird verwendet
Bibliothek Wire in Version 1.0 im Ordner: C:\Desktop_Ext\arduino-1.8.13\hardware\teensy\avr\libraries\Wire  wird verwendet
Bibliothek SD in Version 1.2.2 im Ordner: C:\Desktop_Ext\arduino-1.8.13\hardware\teensy\avr\libraries\SD  wird verwendet
Bibliothek MIDI in Version 5.0.2 im Ordner: C:\Desktop_Ext\arduino-1.8.13\hardware\teensy\avr\libraries\MIDI  wird verwendet
Bibliothek USBHost_t36 in Version 0.1 im Ordner: C:\Desktop_Ext\arduino-1.8.13\hardware\teensy\avr\libraries\USBHost_t36  wird verwendet
Bibliothek TeensyThreads in Version 1.0.1 im Ordner: C:\Desktop_Ext\arduino-1.8.13\hardware\teensy\avr\libraries\TeensyThreads  wird verwendet
Bibliothek CircularBuffer in Version 1.3.3 im Ordner: C:\Users\cw.Mero\Documents\Arduino\libraries\CircularBuffer  wird verwendet
Bibliothek Encoder in Version 1.4.1 im Ordner: C:\Desktop_Ext\arduino-1.8.13\hardware\teensy\avr\libraries\Encoder  wird verwendet
Bibliothek Bounce im Ordner: C:\Desktop_Ext\arduino-1.8.13\hardware\teensy\avr\libraries\Bounce (legacy) wird verwendet
Bibliothek ADC in Version 8.0 im Ordner: C:\Desktop_Ext\arduino-1.8.13\hardware\teensy\avr\libraries\ADC  wird verwendet
Bibliothek EEPROM in Version 2.0 im Ordner: C:\Desktop_Ext\arduino-1.8.13\hardware\teensy\avr\libraries\EEPROM  wird verwendet
Bibliothek SerialFlash in Version 0.5 im Ordner: C:\Desktop_Ext\arduino-1.8.13\hardware\teensy\avr\libraries\SerialFlash  wird verwendet
"C:\\Desktop_Ext\\arduino-1.8.13\\hardware\\teensy/../tools/arm/bin/arm-none-eabi-size" -A "C:\\Users\\CW7930~1.MER\\AppData\\Local\\Temp\\arduino_build_933994/TSynth.ino.elf"
Der Sketch verwendet 271216 Bytes (3%) des Programmspeicherplatzes. Das Maximum sind 8126464 Bytes.
Globale Variablen verwenden 279828 Bytes (53%) des dynamischen Speichers, 244460 Bytes für lokale Variablen verbleiben. Das Maximum sind 524288 Bytes.

`

dwestbury, 2020-11-12:
Thank you for the insight...

Looks like the only library difference is 'Adafruit_GFX_Library'
> I'm using 1.10.2 and you are able to compile successfully with 1.6.1

For completeness, I'm on a Mac with OSX Catalina 10.15.7
Arduino IDE: 1.8.13
Teensyduino: 1.53

I can try to downgrade the Ada GFX lib to see if that makes a difference.

dwestbury, 2020-11-13:
Apparently that was it... I installed 'Adafruit_GFX_Library' v1.6.1 and the code compiles properly.
Thanks for the insight @callimero, much appreciated.

Closed 2020-11-13.

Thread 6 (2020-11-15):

Oscilloscope updating speed

ElectroTechnique, 2020-11-15:
Oscilloscope function needs more work to make updates faster. It's slowed by the zero crossing code that only updates when zero is crossed from positive to negative and then there is a delay while it looks for this again.

ElectroTechnique, 2022-02-07:
Recent merge of improved code. Still not quite like Korg, but we're getting closer.

rolfdegen, 2022-02-16:
Hello tsynth :)  My idee for a better scope screen, I read 4 audio blocks and scaled them to the pixel width of the display.

`
#ifndef Oscilloscope_h_
#define Oscilloscope_h_
#include "AudioStream.h"
#include "ST7735_t3.h"

uint8_t bufferBlock = 0;
uint8_t bufcount = 0;
int16_t prev_pixel_y = 0;
const int lineColor = 0x07B0;
boolean EnvIdelFlag = false;

class Oscilloscope : public AudioStream {
	public:
	Oscilloscope(void) : AudioStream(1, inputQueueArray) {
	}
	virtual void update(void);
	void ScreenSetup(ST7735_t3*);
	void Display(void);
	void AddtoBuffer(int16_t*);

	private:
	audio_block_t *inputQueueArray[1];
	ST7735_t3 *display;
	int16_t buffer[AUDIO_BLOCK_SAMPLES];
};
#endif

void Oscilloscope::ScreenSetup(ST7735_t3 *screen) {
	display = screen;
}

void Oscilloscope::Display() {
	uint8_t pixel_x = 0;
	prev_pixel_y = map(buffer[0], 32767, -32768, -65, 65) + 95;	// 1.Pixel to start drawing scope line
	if (prev_pixel_y < 65) prev_pixel_y = 65;
	if (prev_pixel_y > 126)prev_pixel_y = 126;
	for (uint16_t i = 0; i < AUDIO_BLOCK_SAMPLES - 1; i++) {
		int16_t pixel_y = map(buffer[i], 32767, -32768, -65, 65) + 95;
		if (pixel_y < 65) pixel_y = 65;
		if (pixel_y > 126)pixel_y = 126;
		display->drawLine(pixel_x + 17, prev_pixel_y, pixel_x + 18, pixel_y, lineColor);
		prev_pixel_y = pixel_y;
		pixel_x++;
	}
}

// Scope scale 11.6ms For a better view at low frequencies
void Oscilloscope::AddtoBuffer(int16_t *audio) {
	int16_t prev_audio = 0;
	prev_audio = *audio;
	audio++;
	if (bufferBlock == 0) {
		if (prev_audio > 0 && *audio < 512) {		// change Scope Trigger for more screen refresh
			bufferBlock = 1;
			bufcount = 0;							// ignore the first buffer block for trigger
		}
	}
	else {
		for (uint16_t i = 0; i < 32; i++) {
			buffer[bufcount++] = *audio;
			audio += 4;
		}
		bufferBlock++;
		if (bufferBlock >= 5) {
			bufferBlock = 0;
		}
	}
}

void Oscilloscope::update(void) {
	if (!display) return;
	audio_block_t *block;
	block = receiveReadOnly(0);
	if (block) {
		AddtoBuffer(block->data);
		release(block);
		if (bufferBlock == 0) {
			if (EnvIdelFlag == true) {
				Display();
			}
		}

	}
}
`

Youtube: https://youtu.be/z1ktgjzEsYk?t=2449

ElectroTechnique, 2022-02-18:
Thanks for this. I've been trying slightly different adjustments to the zero crossing code. I like the larger blocks with a sample added to the buffer every fourth sample.  I found this improves stability of the wave (jumping from side to side):

```
void Oscilloscope::AddtoBuffer(int16_t *audio) {
  audio++;
  if (bufferBlock == 0) {
    if (*(audio-1) > -16 && *(audio+3) < 16) {  //<<<<<<<<<<<<<
      bufferBlock = 1;
     bufcount = 0;
    }
  }
```
Still some more work to do.

I've been following this development, hoping to use his oscilloscope code, but it appears to be in assembly or something else compiled: [https://www.youtube.com/watch?v=WJGOIgaY-1s](https://www.youtube.com/watch?v=WJGOIgaY-1s)

rolfdegen, 2022-02-19:
ok. Thanks for information. I will reconsider thescope code.

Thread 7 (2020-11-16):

Volume control reverted back to controlling only headphone volume.

callimero, 2020-11-16:
This comment made me wonder: In the build guide we connect the TRS Jacks to the Headphone Out on the Audio Board... I did not think about this so far, but there is also a Line Out which is more suitable for going to a Mixer, why not using this?

ElectroTechnique, 2020-11-22:
Because people are more likely to want to attach to something where they can alter the volume and the headphone jack on the audio board is unsuitable (as is the USB socket on the Teensy) for repeated insertions.

ElectroTechnique, 2021-04-14:
Actually the line out is probably better from a connection and noise point of view as it has a common ground with the rest of TSynth.

Closed 2021-04-14.

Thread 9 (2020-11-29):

[SOLVED] Display Image is Skewed on ST7735

dwestbury, 2020-11-29:
Has anyone experienced a skewed image on their LCD display?

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

The display doesn't appear to have any physical adjustments, so wondering if there's a way to fix this within the code?

Using library Audio at version 1.3...
Using library SPI at version 1.0...
Using library Adafruit_GFX_Library at version 1.6.1...
Using library Wire at version 1.0...
Using library SD at version 1.2.2...
Using library MIDI at version 5.0.2...
Using library USBHost_t36 at version 0.1...
Using library TeensyThreads at version 1.0.1...
Using library CircularBuffer at version 1.3.3...
Using library Encoder at version 1.4.1...
Using library Bounce...
Using library ADC at version 8.0...
Using library EEPROM at version 2.0...
Using library SerialFlash at version 0.5...
Using library Adafruit_BusIO at version 1.6.0...

-Darrell

sdh7, 2020-12-01:
I had the same issue. This may help-

In ST7735Display.h, in the setupDisplay() function at the bottom, change
tft.initR(INITR_GREENTAB);

to

tft.initR(INITR_BLACKTAB);

and then set tft.invertDisplay(false) instead of true, so that the background is black.

YMMV, as these cheapo displays apparently vary quite a bit. My display was a green-tab one, but had to be changed to INITR_BLACKTAB to work properly.

dwestbury, 2020-12-01:
Ah, brilliant guidance @sdh7 ...

The recommended changes worked like a **_charm_**...

`void setupDisplay() {
  tft.useFrameBuffer(true);
  tft.initR(INITR_BLACKTAB);
  tft.setRotation(3);
  tft.invertDisplay(false);
  renderBootUpPage();
  tft.updateScreen();
  threads.addThread(displayThread);
}`

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

Gerassic426, 2020-12-11:
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

THANK YOU SO MUCH MY GUY, this really helped me a lot, my screen had parts with random pixels and now it's smooth plus I have more space to work with!!! thank you, thank you, thank you!!

Closed 2020-12-01.

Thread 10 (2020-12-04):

Blank sccreen issue

antoniograzioli, 2020-12-04:
I just finieshd building mine, I connect a USB cable to the Teesny4.1 or a USB cable to the USB connector on the board,, the display lihgts up, but it stays completely blank.
Any idea of what/where to troubleshoot?

antoniograzioli, 2020-12-04:
nevermind, it was simply the female headers not making a good contact with some of the Teensy pins...

Closed 2020-12-04.

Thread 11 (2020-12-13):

100 Ohm Resistor on Display SCK is Not Eliminating Audio Noise?

dwestbury, 2020-12-13:
I was hearing the popping and static noise that others were complaining about, so I went ahead and cut the PCB trace for the display clock (SCK) and added in a 100 Ohm resistor as noise reduction bridge, but to my ears there's nearly no difference?

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

Curious whether any other potential sources of noise are being investigated? In my case it's not terrible, but it is clearly perceptible.

ElectroTechnique, 2020-12-18:
Hello Darrell, are you sure that you've cut completely through the SCK track? I've compared before and after, and the resistor does make a significant reduction in noise.

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

dwestbury, 2020-12-18:
I actually peeled off the section of the copper trace leading from my cut on the board to the SDA pin.

Another area I need to investigate as a possible noise source is the dupont connector I made, so I can remove the teensy, rather than soldering it directly to the PCB.

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

nfroeschl, 2020-12-29:
It looks like I have the same problem here. The resistor is in place but the noise (volume independent) is still there.
It look like it soming from any kind of computer USB. With a powerbank away from the computer it is not there.

Any solutions so far ?

ElectroTechnique, 2020-12-31:
If it goes away when you change the power source, then it's coming from that. Be careful with ground loops.

ElectroTechnique, 2021-01-11:
I can confirm that the V1.3 PCB which has a slightly re-routed display SCK track with a 100ohm resistor, is much quieter. Bypassing the 100ohm resistor increases the clock noise significantly.

Closed 2021-01-11.

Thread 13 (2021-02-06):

teensy 4.1 usb client wires pads

snowsh01, 2021-02-06:
Note to be extra careful when soldering the USB jumper wires to the Teensy 4.1 D+ and D- pads. Compared to previous Teensy boards, the 4.1 pads are tiny and very weak. any movement of the wires will likely result in the pads pulling off.

Looking at the Teensy 4.1 schematics a there is fix in the event this occurs but I am yet to perform the fix.

Fix:

If you have damaged the pads, you could connect D+ and D- via U5 pins 6 and 5 respectively

https://www.pjrc.com/teensy/schematic.html

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

philippejadin, 2021-02-16:
I destroyed mine quickly indeed. I'd advice to use very thin wire, solder them like shown in the user guide, and right after put a drop of hot glue to protect the pads and the wires. Too late for me :-/

snowsh01, 2021-02-16:
Yep. I killed mine and learnt the hard way.... Unfortunately there seems to be no easy way to solder in elsewhere

philippejadin, 2021-02-16:
It's not that bad, you can use the micro usb instead for conencting and programming, and if/when it get destroyed, you can unsolder it, and connect back the D+ D- wires from underneath the connector. I would only do it if the micro usb got destroyed because it's probably hard surgery to remove the micro usb connector without touching the rest. It's imho a negative point of teensy : they are too small :-)

antoniograzioli, 2021-02-25:
too late for me as well, i soldered them , they were working, but after some rremoval/reinserts of the teensy they fell apart...

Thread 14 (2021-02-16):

Adding reverb?

philippejadin, 2021-02-16:
I have no idea if there is processing power left and if it could be done easily, but it would be great a have a reverb effect available globally in the setting maybe?

What a cool sounding synth! (happy builder from just yesterday)

antoniograzioli, 2021-02-25:
yeah, a nice reverb would be cool, but I guess there's not enoughr room on the Teensy to run a reverb algo ;-)
I have been working on a similar poly-synth with reverb on a Teensy 3.2...anyway, we'll see...

Closed 2021-03-09.

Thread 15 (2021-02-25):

No USB-MIDI on Mac?

antoniograzioli, 2021-02-25:
I can program the Teensy of my TSynth using the latest .hex (2.10) successfully.
When I connect the Teensy to my PC, it is seen as a MIDI device and I can play it using MIDI-USB.
On Mac (High Sierra) , the TSynth is NOT seen as a MIDI device but as an Audio device (?!?!?)
(I am simply connecting the Tsynth using the Micro-USB port on the Teensy...)
Using the 5-pin DIN Connector for MIDI works on both platforms.

ElectroTechnique, 2021-03-09:
Sorry, I can't test. Can you go to forum.pjrc.com and ask there, they'll be in a better position to help.

Closed 2021-04-14.

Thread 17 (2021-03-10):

Pots

katjap, 2021-03-10:
It looks like all the pots are used as voltage dividers so 100k pots should work just as well right?
I ask in Issues because I have 100+ 100k RV09s on hand and zero in 33k, and I suspect that others who usually work in the Kosmo synth format likely also have a bunch of 100k RV09s, so it would be nice for everyone to be able to see an answer.

Thanks!

ElectroTechnique, 2021-03-11:
100k pots will work but there will be greater susceptibility to noise due to the lower current. I would not recommend them. TSynth uses 10k pots and these have 0.1uf caps and code to deal with noise that causes parameter changes. I would buy 10Ks, don't risk problems with 33 pots that you can't easily desolder.

Closed 2021-03-11.

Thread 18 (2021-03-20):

What features are possible?

winder, 2021-03-20:
Sorry for the vague open-ended question, let me explain. I'm a programmer by day with some electronics and audio hobbies, recently I've been interested in playing with different sounds and stumbled upon the TSynth project. Looking at the code as a software developer I see a lot of opportunity for additional features (i.e. arpeggiator, mono mode + note priorities, etc).

If I spent the time on the code, what sort of features could the teensy handle it? An arpeggiator? What about a split mode?

In general, if you had all the time and inspiration in the world, what other features would be possible/reasonable?

I'm new to this hobby, so I was specifically looking at what some other polysynths have, like the Korg Minilogue:
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

ElectroTechnique, 2021-03-22:
I opted not to include an arpeggiator or sequencer because it's a MIDI synth and these features are better provided by other equipment usually. Multi-timbrality would be a good feature and shouldn't cause any extra CPU load or RAM issues.

remip, 2021-03-22:
A nice feature should be to add drum kits, with different sounds (presets) mapped to midi keys with multi-timbrality

winder, 2021-03-24:
Thanks for the feedback. Looking into the teensy a bit further, this board and the audio library are much more powerful than I realized.

I think a chord mode might be a good way to get started.

For multi timbral mode what exactly do you have in mind? Would I be able to configure a different patch per oscillator? I guess something like that would need to be configured on a computer, which isn't quite as fun as doing it all in the hardware.

callimero, 2021-03-24:
Yea, have fun!

Keep in mind that for a "broad" user base you need to fit it in the Panel-UI. So basically encoder and three knobs. Too much menu diving will lessen the experience of the many knobs.

It took me some time to get how to extend the menus. (but I am no developers anyhow).

Closed 2021-04-14.

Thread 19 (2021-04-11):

PRIORITY - Crashes

ElectroTechnique, 2021-04-11:
Seem to be getting crashes, usually when changing patches. Could be on accessing SD card and loading patch data. Teensyduino 1.54 has improved SD card performance (Bill Greiman's SdFat library).

Never saw these crashes on T3.6 (PCB rev 1.1), but the code is different!

callimero, 2021-04-15:
Yea, encountered these crashes too. Could never see a pattern and so.... I ignored it.

ElectroTechnique, 2021-05-22:
TeensyDuino1.54 may be more promising, the current beta 9 works fine, just delete data_bandlimit_step.c from your TSynth folder because bandlimited waveforms are now included in the audio library.

ElectroTechnique, 2021-06-25:
Haven't had a crash in a while, so closing this.

Closed 2021-06-25.

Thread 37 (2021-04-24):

Make sure audio objects are created in order

winder, 2021-04-24:
I was reading about the audio connections here:
https://www.pjrc.com/teensy/td_libs_AudioConnection.html

At the end it says:
> Audio objects should be created in the order data is processed, inputs, playback and synthesis, then effects, filters, mixers, and lastly outputs.
>
> Connections are most efficient when made from an earlier object (in the order they are created) to a later one. Connections from a later object back to an earlier object can be made, but they add a 1-block delay and consume more memory to implement taht delay.

Most of the objects at the top of AudioPatching.h are not used until the end of the processing, so they should probably be rearranged.

ElectroTechnique, 2021-04-26:
The objects are in their current order because they don't cause any audible problems. Some objects will feedback to earlier ones in the data flow and must be created before these earlier objects. Moving the objects around MUST be done very carefully with frequent testing, as noise artifacts are easily introduced. When the library was created, they probably didn't foresee anyone creating a complicate polysynth.

Closed 2021-05-15.

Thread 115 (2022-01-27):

Loss of voices 10 & 11 (also 9)

ElectroTechnique, 2022-01-27:
Voices 10 and 11 are lost and sometimes 9. Difficult to reproduce but occurs enough times to be a concern. Panic and patch changing doesn't solve.

ElectroTechnique, 2022-07-25:
This is reliably reproduceable when the synth is powered via a pc and has not been powered for a couple of hours. Very odd problem. Restarting power or using a powerbank is ok.

ElectroTechnique, 2023-05-03:
Seems to be linked with using exp shape envelopes on amp.

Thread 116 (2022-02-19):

AudioProcessorUsageMax() wirh new exp envelope

rolfdegen, 2022-02-19:
Hallo Tsynt

I use the exp envelopes and read AudioProcessorUsageMax() It increases with each note. I can not be reset with AudioProcessorUsageMaxReset(). If I load another patch, the  AudioProcessorUsageMax() drops again.

`// CPU Audio Memory ---------------------------------------------------
	if ((millis() - timer_CPUmon) > 500){
			CPUaudioMem = AudioMemoryUsageMax();
			printCPUmon();
			AudioMemoryUsageMaxReset();
		}`

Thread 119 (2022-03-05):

SD card features

jvitkauskas, 2022-03-05:
I am still waiting for my parts to arrive, so it might be an obvious thing, but: what kind of features require SD card? I see that provided presets take only 16k of space so any card size would be ok and speed rating does not matter at all? Also, can SD card files be accessed via USB or would I need to disassemble the case to insert/remove the card?

ElectroTechnique, 2022-03-06:
Just a small card, speed doesn't really make any difference. No you need to remove the card. I couldn't see a way to make it visible to a pc as a storage device.

Closed 2022-03-09.

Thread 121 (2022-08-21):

Unable to Compile Firmware v2.33

dwestbury, 2022-08-21:
I have the BLACKTAB display issue, so whenever a new firmware becomes available, I need to edit the ST7735Display.h file and recompile.

Running into the following issue when compiling for v2.33...

**From the Teensyduino IDE**

>
`Arduino: 1.8.13 (Mac OS X), TD: 1.53, Board: "Teensy 4.1, Serial + MIDI + Audio, 600 MHz, Faster, US English"

/var/folders/d5/5n5zgcmd6svfhnzwcqx2jjdc0000gn/T/arduino_build_91510/sketch/synth_waveform.cpp.o: In function `BandLimitedWaveformTS::lookup(int)':
**/var/folders/d5/5n5zgcmd6svfhnzwcqx2jjdc0000gn/T/arduino_build_91510/sketch/synth_waveform.cpp:526: undefined reference to `step_table'
collect2: error: ld returned 1 exit status**

Using library Audio at version 1.3 in folder: /Applications/Teensyduino.app/Contents/Java/hardware/teensy/avr/libraries/Audio
Using library SPI at version 1.0 in folder: /Applications/Teensyduino.app/Contents/Java/hardware/teensy/avr/libraries/SPI
Using library Adafruit_GFX_Library at version 1.11.3 in folder: /Users/dwestbury/Documents/Tech_Stuff/Electronics/Arduino/libraries/Adafruit_GFX_Library
Using library Adafruit_BusIO at version 1.6.0 in folder: /Users/dwestbury/Documents/Tech_Stuff/Electronics/Arduino/libraries/Adafruit_BusIO
Using library Wire at version 1.0 in folder: /Applications/Teensyduino.app/Contents/Java/hardware/teensy/avr/libraries/Wire
Using library SD at version 1.2.2 in folder: /Applications/Teensyduino.app/Contents/Java/hardware/teensy/avr/libraries/SD
Using library MIDI at version 5.0.2 in folder: /Applications/Teensyduino.app/Contents/Java/hardware/teensy/avr/libraries/MIDI
Using library USBHost_t36 at version 0.1 in folder: /Applications/Teensyduino.app/Contents/Java/hardware/teensy/avr/libraries/USBHost_t36
Using library TeensyThreads at version 1.0.1 in folder: /Applications/Teensyduino.app/Contents/Java/hardware/teensy/avr/libraries/TeensyThreads
Using library CircularBuffer at version 1.3.3 in folder: /Users/dwestbury/Documents/Tech_Stuff/Electronics/Arduino/libraries/CircularBuffer
Using library Encoder at version 1.4.1 in folder: /Applications/Teensyduino.app/Contents/Java/hardware/teensy/avr/libraries/Encoder
Using library Bounce in folder: /Applications/Teensyduino.app/Contents/Java/hardware/teensy/avr/libraries/Bounce (legacy)
Using library ADC at version 8.0 in folder: /Applications/Teensyduino.app/Contents/Java/hardware/teensy/avr/libraries/ADC
Using library EEPROM at version 2.0 in folder: /Applications/Teensyduino.app/Contents/Java/hardware/teensy/avr/libraries/EEPROM
Using library SerialFlash at version 0.5 in folder: /Applications/Teensyduino.app/Contents/Java/hardware/teensy/avr/libraries/SerialFlash
Error compiling for board Teensy 4.1.
`

ElectroTechnique, 2022-08-24:
Hello, can you update to the latest version of Arduino IDE and Teensyduino and compile?

dwestbury, 2022-08-25:
Updating my Arduino IDE to 1.8.19 and Teensyduno to 1.57 seems to have done the trick...

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

I'm able to compile successfully now...

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

Cheers!

Closed 2022-08-25.

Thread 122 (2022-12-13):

Display only works when ... putting my finger between SDA & SCL pins

Sercurio, 2022-12-13:
I guys after some troubleshooting, I finally find a way to make the display works. At startup, I put my finger on the display pins, and it magically works. I don't know what is the effect of doing that. Should I add a capacitor between some pins ?
Thanks u

Sercurio, 2022-12-13:
Duplicate sorry

Closed 2023-01-05.

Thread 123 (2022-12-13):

Display only works when ... putting my finger between SDA & SCL pins

Sercurio, 2022-12-13:
I guys after some troubleshooting, I finally find a way to make the display works. At startup, I put my finger on the display pins, and it magically works. I don't know what is the effect of doing that. Should I add a capacitor between some pins ?
Thanks u

ElectroTechnique, 2023-01-05:
You have a soldering problem.

Closed 2023-01-05.

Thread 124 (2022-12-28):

Can you still build one of these for $99?

CptanPanic, 2022-12-28:
The README says it costs $99 to build, but stuff can't find singles of PCB or Front Panel. Does anyone know how to build less than the $355 for the full tindie kit.

ElectroTechnique, 2023-01-05:
Hello, it'll cost around $99 just for a PCB and the parts to get it running. The enclosure is something else and depends on whether you make it yourself.

CptanPanic, 2023-01-05:
> Hello, it'll cost around $99 just for a PCB and the parts to get it running. The enclosure is something else and depends on whether you make it yourself.

@ElectroTechnique
Can you tell me how to get the PCB so I can get under the $99 including the parts?

Closed 2023-01-05.

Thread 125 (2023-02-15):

First Voice in Unisono Mode 1

rolfdegen, 2023-02-15:
I have a question about Unisono Mode1 in TSynth 4.1. In the old Firmware (Version 2.00 ) you don't use DETUNE for the 1st voice. The Oscillator Frequency for Midi Note A4 is always 440Hz.

Firmware 2.00
`void updateVoice1() {
  if (unison == 1) {
    waveformMod1a.frequency(NOTEFREQS[voices[0].note + oscPitchA]);
    waveformMod1b.frequency(NOTEFREQS[voices[0].note + oscPitchB] * (detune + ((1 - detune) * DETUNE[notesOn - 1][1])));
  } else if (unison == 2) {
    waveformMod1a.frequency(NOTEFREQS[voices[0].note + oscPitchA + CHORD_DETUNE[0][chordDetune]]) ;
    waveformMod1b.frequency(NOTEFREQS[voices[0].note + oscPitchB + CHORD_DETUNE[0][chordDetune]] * CDT_DETUNE);
  } else {
    waveformMod1a.frequency(NOTEFREQS[voices[0].note + oscPitchA]);
    waveformMod1b.frequency(NOTEFREQS[voices[0].note + oscPitchB] * detune);
  }
}`

In the latest firmware version 2.33, the oscillator frequency for the 1st voice changes with the DETUNE.

Firmware 2.33
 ` void updateVoice(VoiceParams &params, uint8_t notesOn) {
            Patch& osc = this->patch();

            if (params.unisonMode == 1) {
                int offset = 2 * this->index();
                osc.waveformMod_a.frequency(NOTEFREQS[this->_note + params.oscPitchA] * (params.detune + ((1 - params.detune) * DETUNE[notesOn - 1][offset])));
                osc.waveformMod_b.frequency(NOTEFREQS[this->_note + params.oscPitchB] * (params.detune + ((1 - params.detune) * DETUNE[notesOn - 1][offset + 1])));
            } else if (params.unisonMode == 2) {
                // TODO: This approach doesn't make sense with voices spread across multiple timbres.
                osc.waveformMod_a.frequency(NOTEFREQS[this->_note + params.oscPitchA + CHORD_DETUNE[this->index()][params.chordDetune]]) ;
                osc.waveformMod_b.frequency(NOTEFREQS[this->_note + params.oscPitchB + CHORD_DETUNE[this->index()][params.chordDetune]] * CDT_DETUNE);
            } else {
                osc.waveformMod_a.frequency(NOTEFREQS[this->_note + params.oscPitchA]);
                osc.waveformMod_b.frequency(NOTEFREQS[this->_note + params.oscPitchB] * params.detune);
            }
        }`

The base frequency of oscillator 1 in voice 1 (440 Hz) changes with the DETUNE setting. Is that correct ?

Greetings from germany and have a nice time :)

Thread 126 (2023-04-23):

Feature Request: ability to select screen "type" without uploading different versions of firmware

worsco, 2023-04-23:
I was thinking about a method of configuring the display during initial boot instead of having to upload different versions of the firmware.

There are three buttons below the display: "Settings", "Save", and "Back" and to the right of the display is the rotary encoder which has the ability to be pressed to "confirm" a selection.

Binary math provides us with eight (8) different "settings" on power-up:

```
   3 2 1*
0: 0 0 0 no buttons pressed power-up == no state change
1: 0 0 1 default
2: 0 1 0
3: 0 1 1
4: 1 0 0
5: 0 1 0
6: 1 1 0
7: 1 1 1

*Buttons:
1 == Settings
2 == Save
3 == Back
```

On initial boot-up, what if the three buttons were used to select one of seven possible screen settings (not that there are 7 current display setting possibilities, but there is the ability to select that many different config options on initial power-up).

Here is my pseudo code:
```
1. If any of the three buttons are pressed on power-up:
   a. based on the button pressed, choose the configuration setting and configure display
   b. initialize screen with setting chosen
   c. on the display, ask confirmation question "Is display correct/viewable?"
      1. 10 second loop count down
      2. during loop, press down on rotary to confirm
      3. If rotary pressed down,
         a. if SD card exists, then
            1. create file screen setting (or write-over existing file)
            2. write screen configuration setting (assumes one file used the screen setting)
            3. close file
         b. else exit loop & continue
      4. after 10 second loop (rotary never pressed), continue  w/o saving
         (perhaps the logic could it loop into a sequence where you can try another key combo,
          or would it be better to revert to the "default" screen config and continue booting?)

3. if no buttons pressed on initial power-up
   a. look for config file on SD card for screen configuration file
   b. if file found
       1. parse contents
       2. validate setting:
          a. if valid, set screen config to setting chosen
          b. if invalid, use "default" screen setting (from a previously set constant variable)
```

worsco, 2023-04-23:
Maybe the first iteration of configuring the screen would to just implement the "Settings/Save/Back" button combos to select which configuration to use on power-on.  The next phase would to make the setting persistent after selecting.

wilksy, 2023-04-23:
I've actually done this. Well, I've actually rewritten most of the display code to work with animated dials and visual graphs for the waveforms.

Give me a week it two and I'll figure out how to upload, I've actually never hues GitHub for Collab projects.

Unless someone fancies taking the code and working with it?

worsco, 2023-04-23:
> Give me a week it two and I'll figure out how to upload, I've actually never hues GitHub for Collab projects.
>
> Unless someone fancies taking the code and working with it?

@wilksy

Did you fork this repo in github?  If so, you can post your changes to your fork and the submit PRs (Pull Requests) to the original repo.  If you post your code in your own repo, I can take a look and see your handy work.

Thanks in advance.

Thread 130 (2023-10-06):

error: ordered comparison of pointer with integer zero ('char* (*)(const char*, int)' and 'int')

danielkinahan, 2023-10-06:
Trying to verify this project and getting this error and another one. Some info

- Arduino IDE 2.2.1
- Teensyduino 1.58.1
- Using latest main commit e2fd7cd
- Arduino IDE Tools Settings:
  - Board: "Teensy4.1"
  - USB Type: "Serial + MIDI + Audio"
  - CPU Speed: "600MHz"
  - Optimize: "Faster"
- CircularBuffer - AgileWare: 1.3.3
- Adafruit GFX Library: 1.11.8
- Windows 11

Full error message:
```
C:\TSynth-Teensy4.1\TSynth\effect_ensemble.cpp: In member function 'int16_t AudioEffectEnsemble::interpBuffer(float)':
C:\TSynth-Teensy4.1\TSynth\effect_ensemble.cpp:267:16: error: ordered comparison of pointer with integer zero ('char* (*)(const char*, int)' and 'int')
  267 |   else if(index<0) index2+=ENSEMBLE_BUFFER_SIZE;
      |           ~~~~~^~
In file included from C:\TSynth-Teensy4.1\TSynth\Audio.h:67,
                 from C:\TSynth-Teensy4.1\TSynth\TSynth.ino:48:
C:\TSynth-Teensy4.1\TSynth\synth_dc.h: In member function 'void AudioSynthWaveformDcTS::amplitude(float, float)':
C:\TSynth-Teensy4.1\TSynth\synth_dc.h:118:17: error: 'void AudioSynthWaveformDcTS::amplitude(float, float)' causes a section type conflict with 'int compare(const void*, const void*)'
  118 |   FLASHMEM void amplitude(float n, float milliseconds) {
      |                 ^~~~~~~~~
In file included from C:\TSynth-Teensy4.1\TSynth\TSynth.ino:60:
C:\TSynth-Teensy4.1\TSynth\PatchMgr.h:74:14: note: 'int compare(const void*, const void*)' was declared here
   74 | FLASHMEM int compare(const void *a, const void *b) {
      |              ^~~~~~~
```

danielkinahan, 2023-10-07:
I have verified that I'm also getting this on the latest released tag V2.33

danielkinahan, 2023-10-07:
For the first error it's now obvious to me after looking at the code that `index` should be `index2`. I will make a PR with that simple change soon.

I am leaning towards thinking the second error is the result of my build steps. In the FLASHMEM section
`PatchMgr.h - int compare(const void*, const void*)`
is already declared and causing a section type conflict with
`synth_dc.h - void AudioSynthWaveformDcTS::amplitude(float, float)`

Research for this tells me to declare these objects into different sections initially and combine them with a linker instruction but I'm not sure how to achieve that in this codebase. I suspect that something in TeensyDuino might have changed since the FLASHMEM definition comes from that library.

ElectroTechnique, 2023-11-20:
Fixed in V2.35.

Closed 2023-11-20.

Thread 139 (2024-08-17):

Bug in effect_envelope

h4yn0nnym0u5e, 2024-08-17:
As noted on the Teensy forum (https://forum.pjrc.com/index.php?threads/teensy-exponential-envelopes.75646/), there's a bug in the exponential envelope which shows up with a non-zero delay setting. I can't find a further upstream source than this one, though your commit log suggests there might be one... I think we're seeking Vince R. Pearson.

ElectroTechnique, 2024-08-18:
Yes that's correct - [https://github.com/vipear](https://github.com/vipear)

h4yn0nnym0u5e, 2024-08-18:
Thanks. Looks like he’s not been active for 3 years, would it be better to send the PR direct to you in this repo?

ElectroTechnique, 2024-08-19:
Yes, that's ok. I'll update with any fixes.

Closed 2024-08-26.

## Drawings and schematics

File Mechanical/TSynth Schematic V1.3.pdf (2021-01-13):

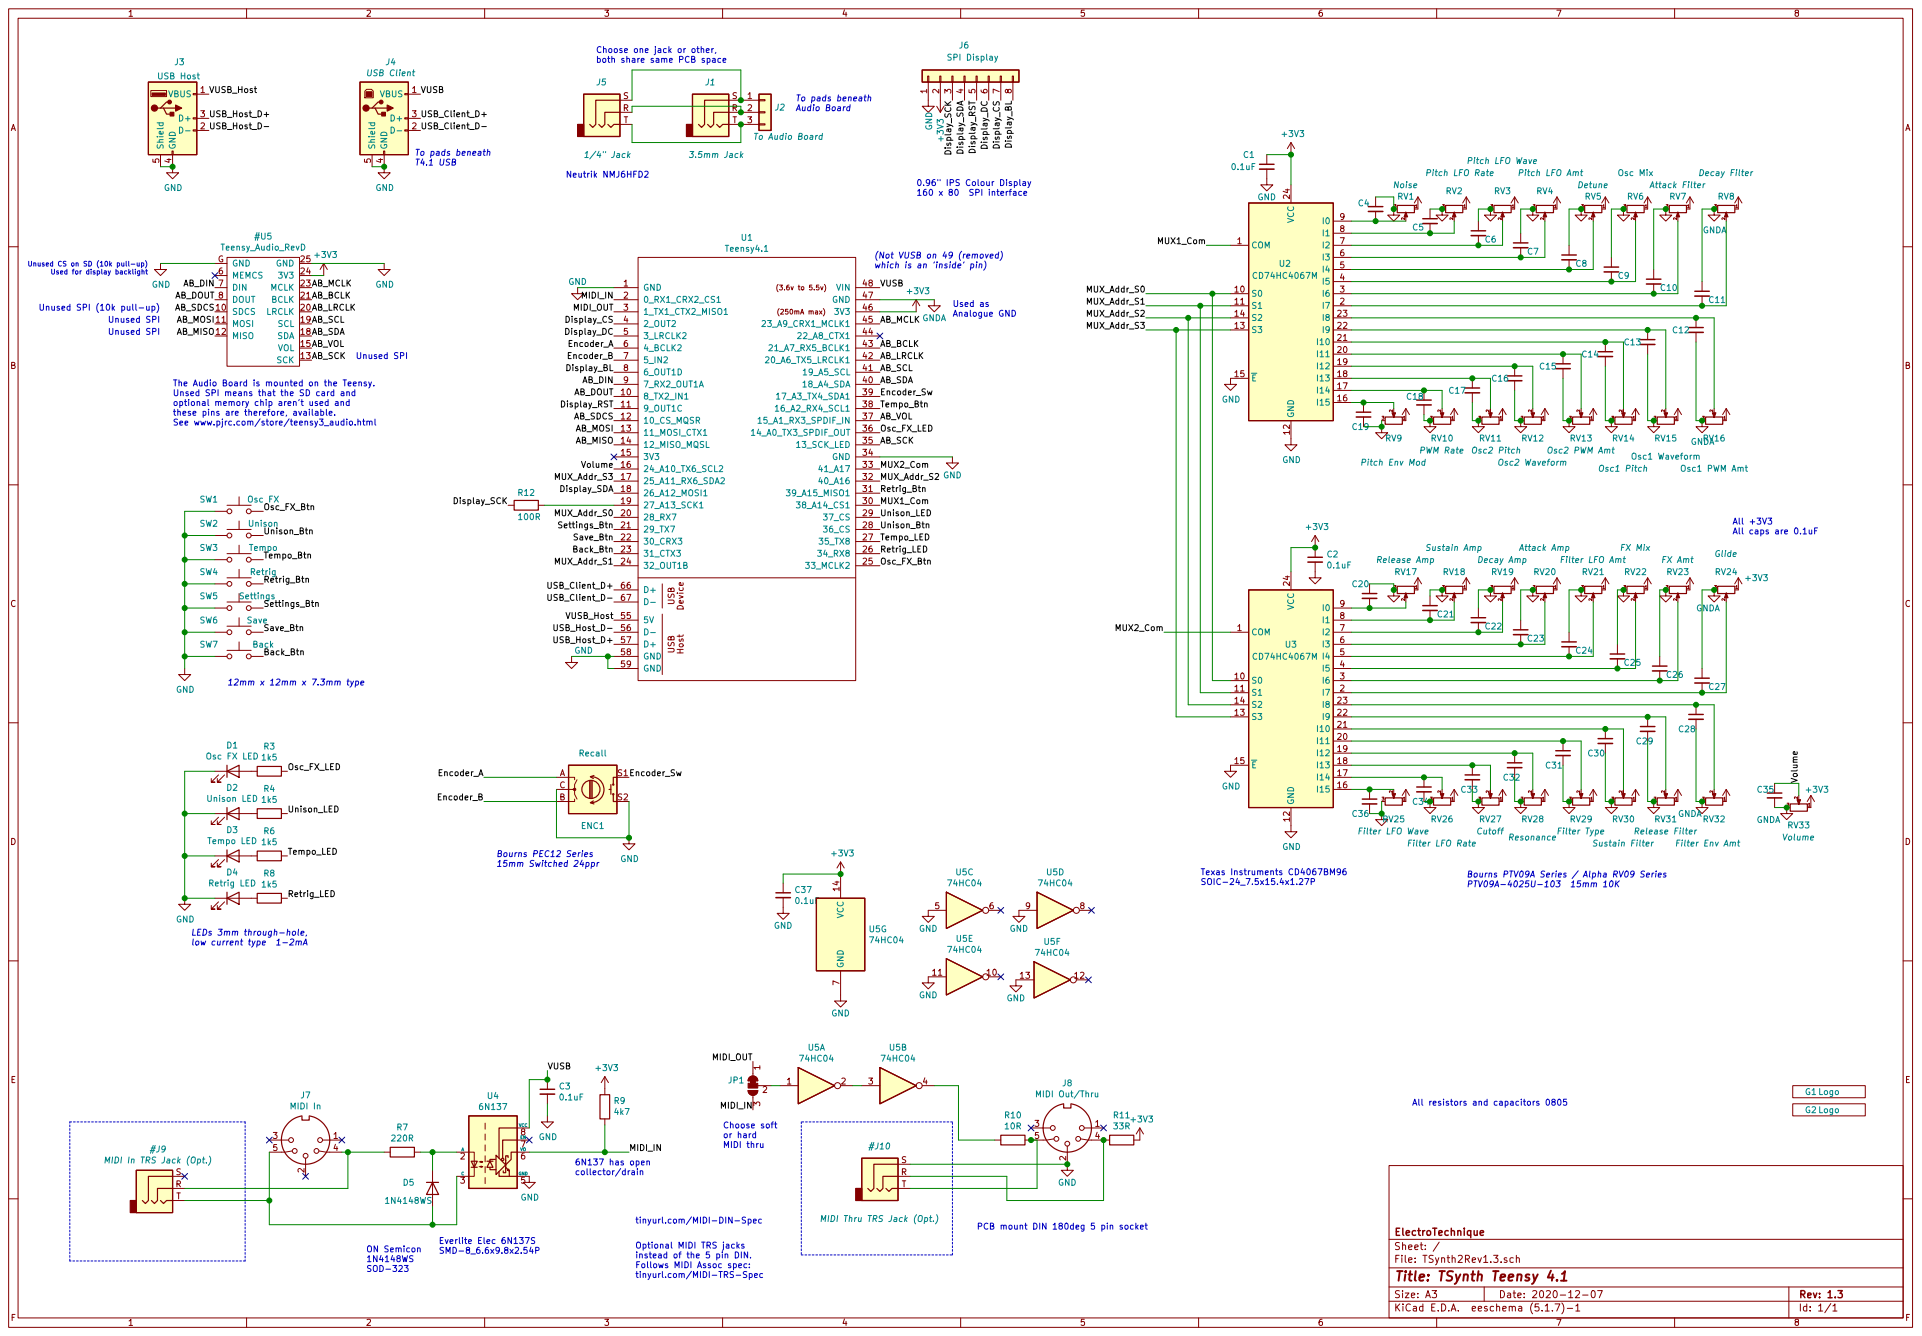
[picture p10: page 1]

Choose one jack or other,

Display_BL VUSB
To pads beneath Audio Board To pads beneath T4.1 USB
USB_Client_D-

3 RV4 Pitch LFO Amt GND

0.96" IPS Colour Display 160 x 80 SPI interface

3RV21 Filter LFO Amt GND

(Not VUSB on 49 (removed)
which is an 'inside' pin)

Unused SPI (10k pull-up)

Unused SPI

The Audio Board is mounted on the Teensy. Unsed SPI means that the SD card and

optional memory chip aren't used and
these pins are therefore, available.
See www.pjrc.com/store/teensy3_audio.html

3RV10 PWM Rate D1 Osc FX LED

All +3V3 All caps are 0.1uF

collector/drain Bourns PEC12 Series 15mm Switched 24ppr

3RV26 Filter LFO Rate GND

3RV32 Filter Env Amt GND

Bourns PTV09A Series / Alpha RV09 Series PTV09A-4025U-103 15mm 10K

J8 MIDI Out/Thru GND

Choose soft or hard MIDI thru

All resistors and capacitors 0805

#J9 MIDI In TRS Jack (Opt.)

#J10 MIDI Thru TRS Jack (Opt.)

tinyurl.com/MIDI-DIN-Spec

PCB mount DIN 180deg 5 pin socket

File: TSynth2Rev1.3.sch Sheet: / ElectroTechnique

Optional MIDI TRS jacks
instead of the 5 pin DIN.
Follows MIDI Assoc spec:
tinyurl.com/MIDI-TRS-Spec

Id: 1/1 Title: TSynth Teensy 4.1

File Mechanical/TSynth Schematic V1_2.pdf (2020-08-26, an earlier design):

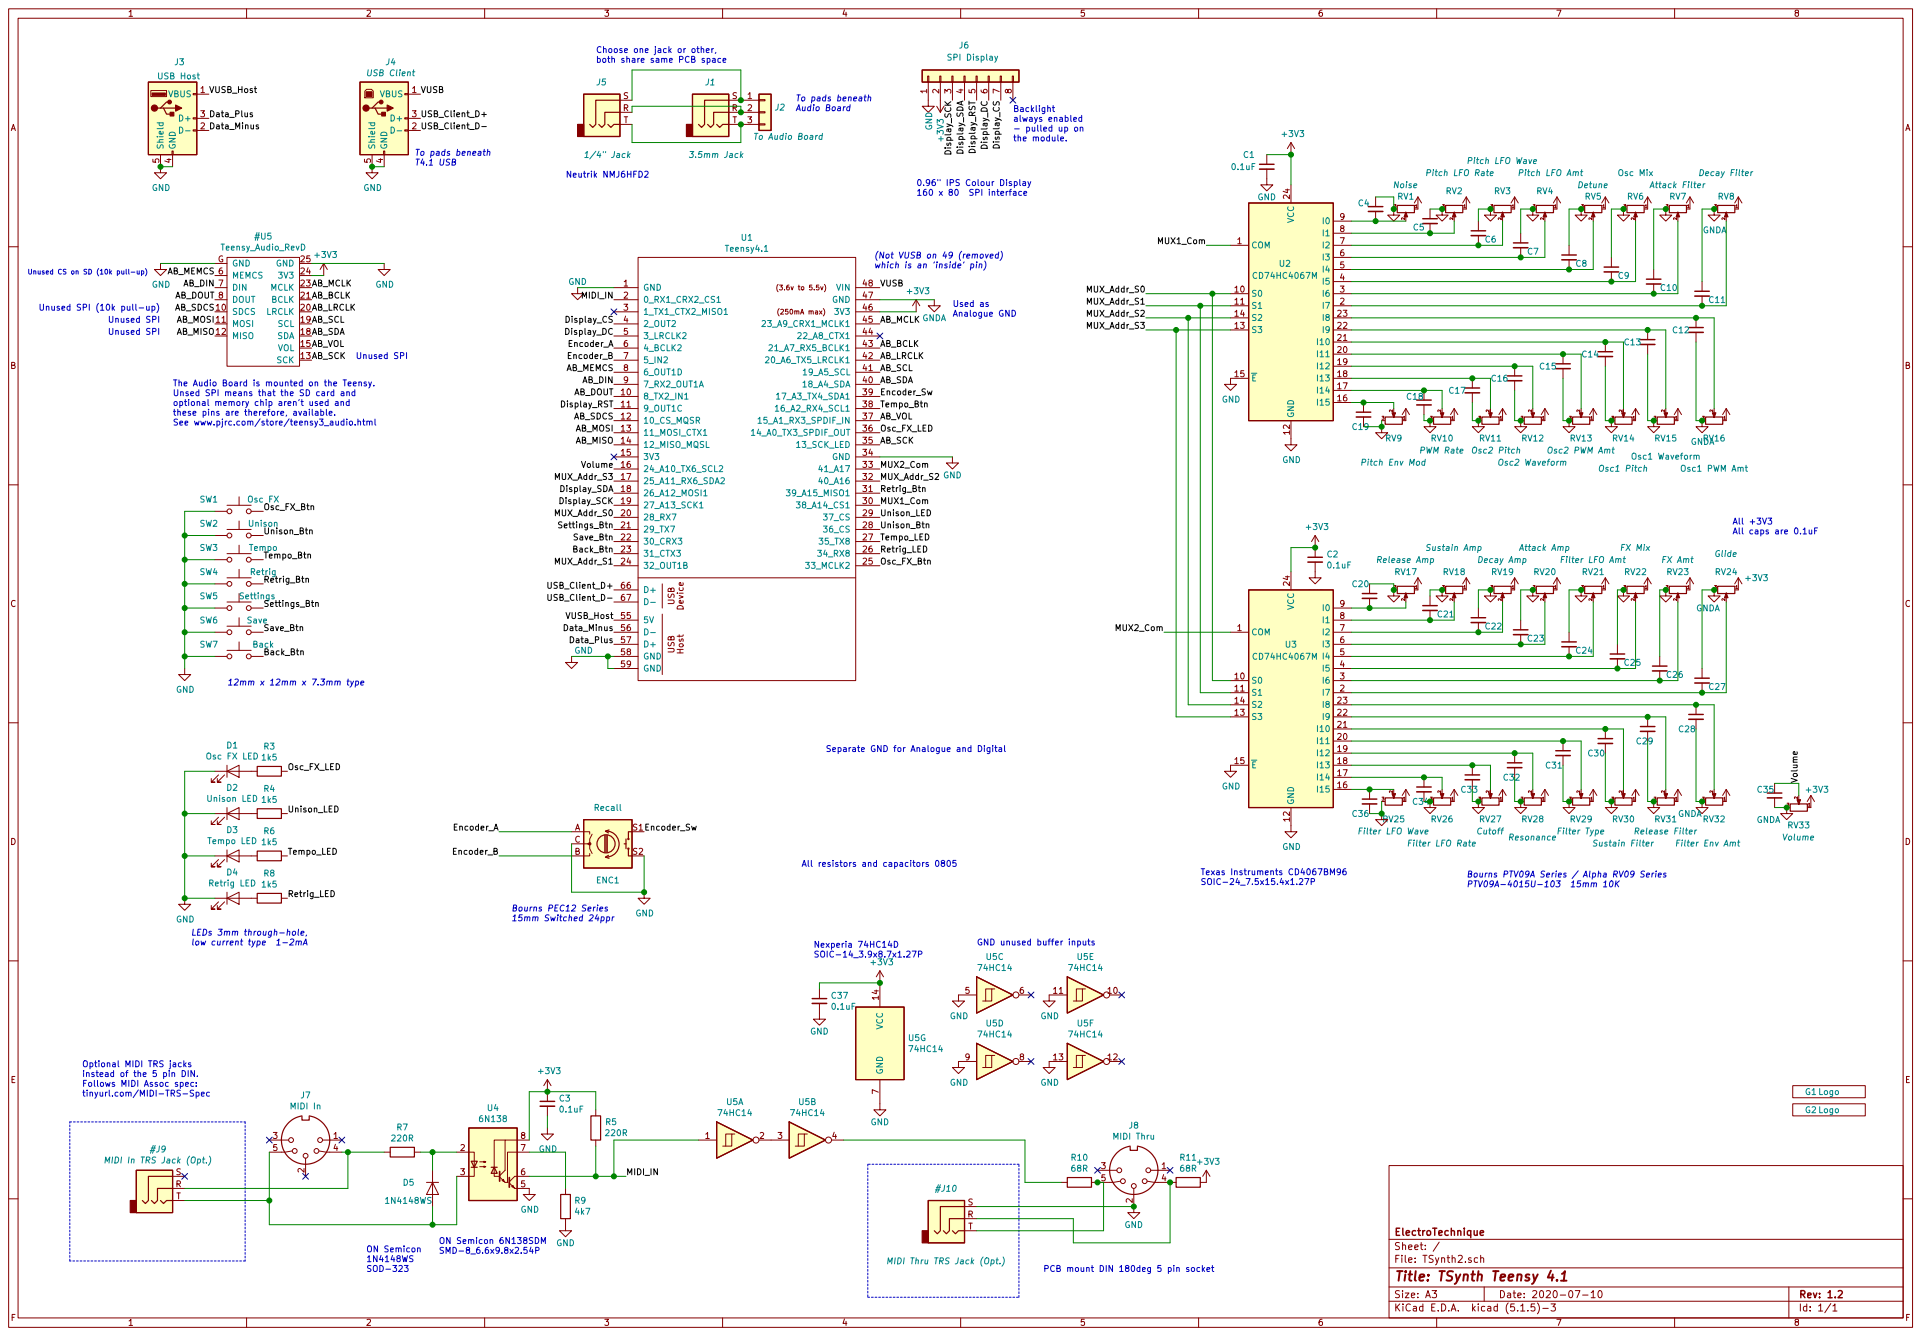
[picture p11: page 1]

both share same PCB space

To pads beneath Audio Board

the module. To pads beneath T4.1 USB

1/4" Jack
0.1uF GND
3 RV4 Pitch LFO Amt GND GND

0.96" IPS Colour Display 160 x 80 SPI interface

(3.6v to 5.5v) Device USB Host USB

(Not VUSB on 49 (removed)
which is an 'inside' pin)

Unused SPI (10k pull-up)

Used as Analogue GND

The Audio Board is mounted on the Teensy. Unsed SPI means that the SD card and

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

3RV10 PWM Rate D1 Osc FX LED

Separate GND for Analogue and Digital

All resistors and capacitors 0805
74HC14 +3V3 GND

Bourns PTV09A Series / Alpha RV09 Series PTV09A-4015U-103 15mm 10K

GND unused buffer inputs

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

#J9 MIDI In TRS Jack (Opt.)

PCB mount DIN 180deg 5 pin socket ON Semicon
SOD-323

Id: 1/1 Title: TSynth Teensy 4.1

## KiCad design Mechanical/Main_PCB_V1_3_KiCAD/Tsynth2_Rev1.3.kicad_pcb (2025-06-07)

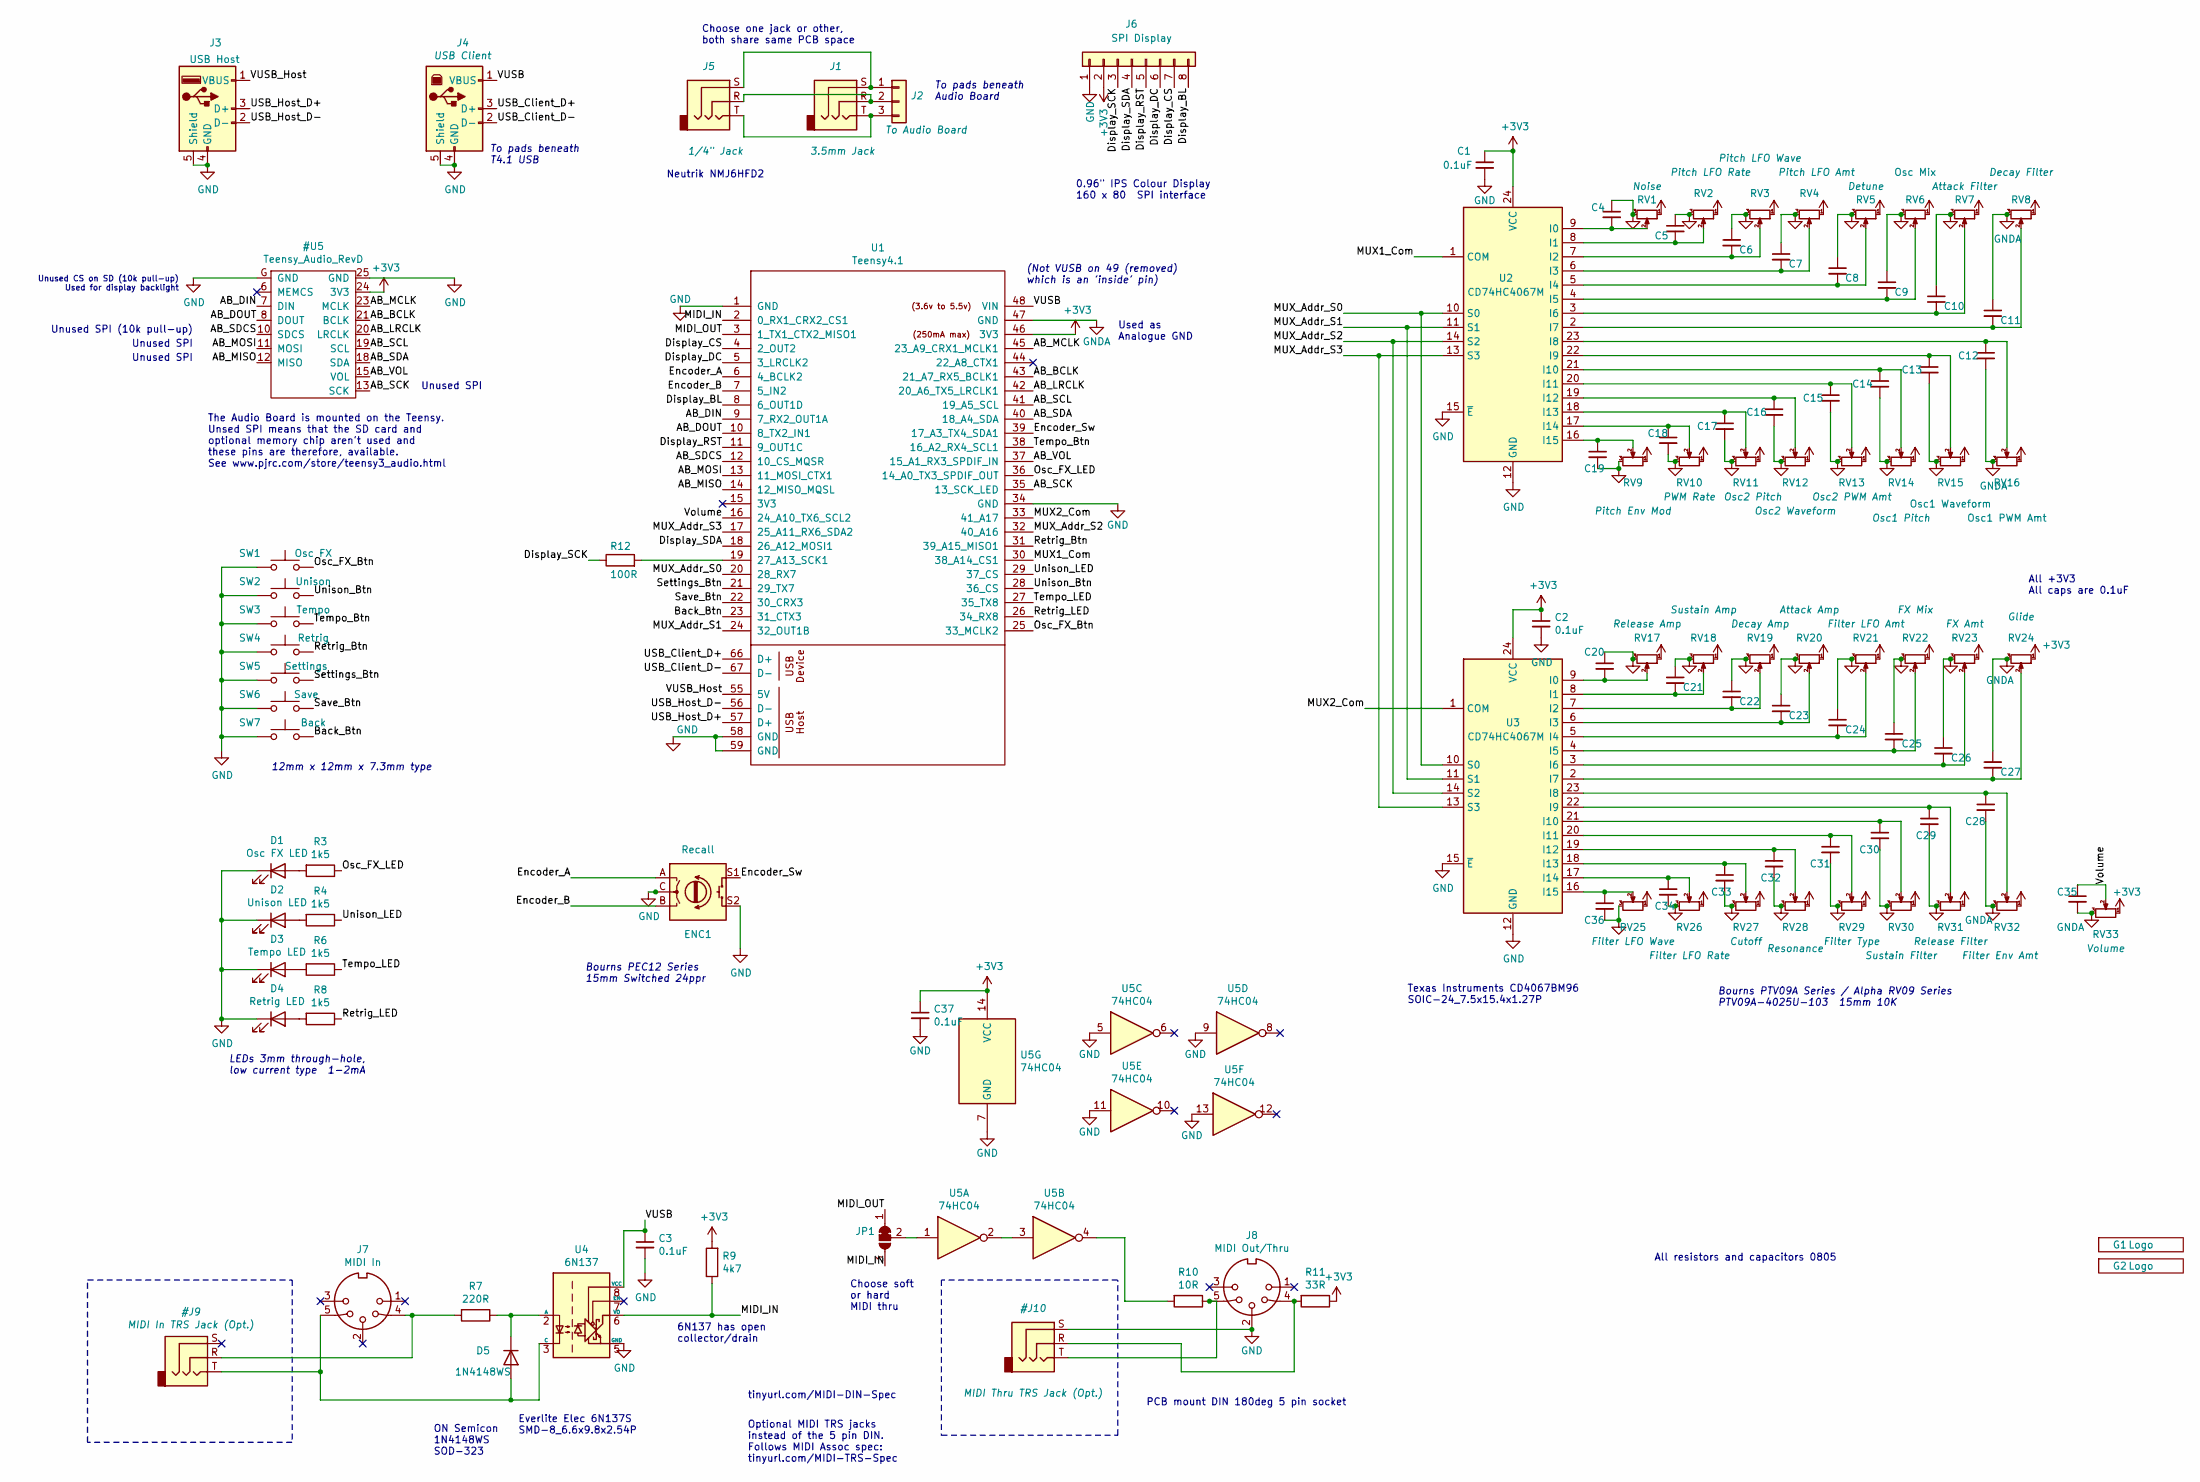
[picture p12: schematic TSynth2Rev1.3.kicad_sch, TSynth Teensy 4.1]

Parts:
C1, C37: 0.1uF; R_0805_2012Metric; LCSC C49678
C2, C3, C4, C5, C6, C7, C8, C9, C10, C11, C12, C13, C14, C15, C16, C17, C18, C19, C20, C21, C22, C23, C24, C25, C26, C27, C28, C29, C30, C31, C32, C33, C34, C35, C36: 0.1uF; R_0805_2012Metric
D1: Osc FX LED; LED_D3.0mm
D2: Unison LED; LED_D3.0mm
D3: Tempo LED; LED_D3.0mm
D4: Retrig LED; LED_D3.0mm
D5: 1N4148WS; D_SOD-323F; LCSC C2128
ENC1: Recall; RotaryEncoder_Alps_EC11E-Switch_Vertical_H20mm
G1, G2: Logo; TSynth PCB Logo 41mm
J1: 3.5mm Jack; Jack_3.5mm_Ledino_KB3SPRS_Horizontal
J2: To Audio Board; PinHeader_1x03_P2.54mm_Vertical
J3: USB Host; USB_A_Stewart_SS-52100-001_Horizontal
J4: USB Client; USB_B_OST_USB-B1HSxx_Horizontal
J5: 1/4" Jack; Jack_6.35mm_Neutrik_NMJ6HFD2_Horizontal
J6: SPI Display; PinHeader_1x08_P2.54mm_Vertical
J7: MIDI In; MIDI_DIN5
J8: MIDI Out/Thru; MIDI_DIN5
JP1: SolderJumper_3_Bridged12; SolderJumper-3_P1.3mm_Bridged12_RoundedPad1.0x1.5mm
R3, R4, R6, R8: 1k5; R_0805_2012Metric; LCSC C4310
R7: 220R; R_0805_2012Metric; LCSC C17557
R9: 4k7; R_0805_2012Metric; LCSC C17673
R10: 10R; R_0805_2012Metric; LCSC C17415
R11: 33R; R_0805_2012Metric; LCSC C17634
R12: 100R; R_0805_2012Metric; LCSC C17408
RV1: Noise; Potentiometer_Bourns_PTV09A-1_Single_Vertical
RV2: Pitch LFO Rate; Potentiometer_Bourns_PTV09A-1_Single_Vertical
RV3: Pitch LFO Wave; Potentiometer_Bourns_PTV09A-1_Single_Vertical
RV4: Pitch LFO Amt; Potentiometer_Bourns_PTV09A-1_Single_Vertical
RV5: Detune; Potentiometer_Bourns_PTV09A-1_Single_Vertical
RV6: Osc Mix; Potentiometer_Bourns_PTV09A-1_Single_Vertical
RV7: Attack Filter; Potentiometer_Bourns_PTV09A-1_Single_Vertical
RV8: Decay Filter; Potentiometer_Bourns_PTV09A-1_Single_Vertical
RV9: Pitch Env Mod; Potentiometer_Bourns_PTV09A-1_Single_Vertical
RV10: PWM Rate; Potentiometer_Bourns_PTV09A-1_Single_Vertical
RV11: Osc2 Pitch; Potentiometer_Bourns_PTV09A-1_Single_Vertical
RV12: Osc2 Waveform; Potentiometer_Bourns_PTV09A-1_Single_Vertical
RV13: Osc2 PWM Amt; Potentiometer_Bourns_PTV09A-1_Single_Vertical
RV14: Osc1 Pitch; Potentiometer_Bourns_PTV09A-1_Single_Vertical
RV15: Osc1 Waveform; Potentiometer_Bourns_PTV09A-1_Single_Vertical
RV16: Osc1 PWM Amt; Potentiometer_Bourns_PTV09A-1_Single_Vertical
RV17: Release Amp; Potentiometer_Bourns_PTV09A-1_Single_Vertical
RV18: Sustain Amp; Potentiometer_Bourns_PTV09A-1_Single_Vertical
RV19: Decay Amp; Potentiometer_Bourns_PTV09A-1_Single_Vertical
RV20: Attack Amp; Potentiometer_Bourns_PTV09A-1_Single_Vertical
RV21: Filter LFO Amt; Potentiometer_Bourns_PTV09A-1_Single_Vertical
RV22: FX Mix; Potentiometer_Bourns_PTV09A-1_Single_Vertical
RV23: FX Amt; Potentiometer_Bourns_PTV09A-1_Single_Vertical
RV24: Glide; Potentiometer_Bourns_PTV09A-1_Single_Vertical
RV25: Filter LFO Wave; Potentiometer_Bourns_PTV09A-1_Single_Vertical
RV26: Filter LFO Rate; Potentiometer_Bourns_PTV09A-1_Single_Vertical
RV27: Cutoff; Potentiometer_Bourns_PTV09A-1_Single_Vertical
RV28: Resonance; Potentiometer_Bourns_PTV09A-1_Single_Vertical
RV29: Filter Type; Potentiometer_Bourns_PTV09A-1_Single_Vertical
RV30: Sustain Filter; Potentiometer_Bourns_PTV09A-1_Single_Vertical
RV31: Release Filter; Potentiometer_Bourns_PTV09A-1_Single_Vertical
RV32: Filter Env Amt; Potentiometer_Bourns_PTV09A-1_Single_Vertical
RV33: Volume; Potentiometer_Bourns_PTV09A-1_Single_Vertical
SW1: Osc FX; SW_PUSH-12mm
SW2: Unison; SW_PUSH-12mm
SW3: Tempo; SW_PUSH-12mm
SW4: Retrig; SW_PUSH-12mm
SW5: Settings; SW_PUSH-12mm
SW6: Save; SW_PUSH-12mm
SW7: Back; SW_PUSH-12mm
U1: Teensy4.1; Teensy41
U2, U3: CD74HC4067M; SOIC-24W_7.5x15.4mm_P1.27mm; LCSC C496123
U4: 6N137; SMDIP-8_W9.53mm; LCSC C110020
U5: 74HC04; SOIC-14_3.9x8.7mm_P1.27mm; LCSC C5605

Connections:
/Back_Btn: SW7.2, U1.23 (31_CTX3)
/Display_BL: J6.8, U1.8 (6_OUT1D)
/Display_CS: J6.7, U1.4 (2_OUT2)
/Display_DC: J6.6, U1.5 (3_LRCLK2)
/Display_RST: J6.5, U1.11 (9_OUT1C)
/Display_SCK: J6.3, R12.1
/Display_SDA: J6.4, U1.18 (26_A12_MOSI1)
/Encoder_A: ENC1.A, U1.6 (4_BCLK2)
/Encoder_B: ENC1.B, U1.7 (5_IN2)
/Encoder_Sw: ENC1.S1, U1.39 (17_A3_TX4_SDA1)
/MIDI_IN: JP1.3 (B), R9.1, U1.2 (0_RX1_CRX2_CS1), U4.6 (VO)
/MIDI_OUT: JP1.1 (A), U1.3 (1_TX1_CTX2_MISO1)
/MUX1_Com: U1.30 (38_A14_CS1), U2.1 (COM)
/MUX2_Com: U1.33 (41_A17), U3.1 (COM)
/MUX_Addr_S0: U1.20 (28_RX7), U2.10 (S0), U3.10 (S0)
/MUX_Addr_S1: U1.24 (32_OUT1B), U2.11 (S1), U3.11 (S1)
/MUX_Addr_S2: U1.32 (40_A16), U2.14 (S2), U3.14 (S2)
/MUX_Addr_S3: U1.17 (25_A11_RX6_SDA2), U2.13 (S3), U3.13 (S3)
/Osc_FX_Btn: SW1.2, U1.25 (33_MCLK2)
/Osc_FX_LED: R3.1, U1.36 (14_A0_TX3_SPDIF_OUT)
/Retrig_Btn: SW4.2, U1.31 (39_A15_MISO1)
/Retrig_LED: R8.1, U1.26 (34_RX8)
/Save_Btn: SW6.2, U1.22 (30_CRX3)
/Settings_Btn: SW5.2, U1.21 (29_TX7)
/Tempo_Btn: SW3.2, U1.38 (16_A2_RX4_SCL1)
/Tempo_LED: R6.1, U1.27 (35_TX8)
/USB_Client_D+: J4.3 (D+), U1.66 (D+)
/USB_Client_D-: J4.2 (D-), U1.67 (D-)
/USB_Host_D+: J3.3 (D+), U1.57 (D+)
/USB_Host_D-: J3.2 (D-), U1.56 (D-)
/Unison_Btn: SW2.2, U1.28 (36_CS)
/Unison_LED: R4.1, U1.29 (37_CS)
/VUSB: C3.1, J4.1 (VBUS), U1.48 (VIN), U4.8 (VCC)
/VUSB_Host: J3.1 (VBUS), U1.55 (5V)
/Volume: C35.1, RV33.2, U1.16 (24_A10_TX6_SCL2)
GNDA: C4.1, C5.1, C6.1, C7.1, C8.1, C9.1, C10.1, C11.1, C12.2, C13.2, C14.2, C15.2, C16.2, C17.2, C18.2, C19.2, C20.1, C21.1, C22.1, C23.1, C24.1, C25.1, C26.1, C27.1, C28.2, C29.2, C30.2, C31.2, C32.2, C33.2, C34.2, C35.2, C36.2, RV1.3, RV2.3, RV3.3, RV4.3, RV5.3, RV6.3, RV7.3, RV8.3, RV9.3, RV10.3, RV11.3, RV12.3, RV13.3, RV14.3, RV15.3, RV16.3, RV17.3, RV18.3, RV19.3, RV20.3, RV21.3, RV22.3, RV23.3, RV24.3, RV25.3, RV26.3, RV27.3, RV28.3, RV29.3, RV30.3, RV31.3, RV32.3, RV33.3, U1.47 (GND)
unnamed: C4.2, RV1.2, U2.9 (I0)
unnamed: C5.2, RV2.2, U2.8 (I1)
unnamed: C6.2, RV3.2, U2.7 (I2)
unnamed: C7.2, RV4.2, U2.6 (I3)
unnamed: C8.2, RV5.2, U2.5 (I4)
unnamed: C9.2, RV6.2, U2.4 (I5)
unnamed: C10.2, RV7.2, U2.3 (I6)
unnamed: C11.2, RV8.2, U2.2 (I7)
unnamed: C12.1, RV16.2, U2.23 (I8)
unnamed: C13.1, RV15.2, U2.22 (I9)
unnamed: C14.1, RV14.2, U2.21 (I10)
unnamed: C15.1, RV13.2, U2.20 (I11)
unnamed: C16.1, RV12.2, U2.19 (I12)
unnamed: C17.1, RV11.2, U2.18 (I13)
unnamed: C18.1, RV10.2, U2.17 (I14)
unnamed: C19.1, RV9.2, U2.16 (I15)
unnamed: C20.2, RV17.2, U3.9 (I0)
unnamed: C21.2, RV18.2, U3.8 (I1)
unnamed: C22.2, RV19.2, U3.7 (I2)
unnamed: C23.2, RV20.2, U3.6 (I3)
unnamed: C24.2, RV21.2, U3.5 (I4)
unnamed: C25.2, RV22.2, U3.4 (I5)
unnamed: C26.2, RV23.2, U3.3 (I6)
unnamed: C27.2, RV24.2, U3.2 (I7)
unnamed: C28.1, RV32.2, U3.23 (I8)
unnamed: C29.1, RV31.2, U3.22 (I9)
unnamed: C30.1, RV30.2, U3.21 (I10)
unnamed: C31.1, RV29.2, U3.20 (I11)
unnamed: C32.1, RV28.2, U3.19 (I12)
unnamed: C33.1, RV27.2, U3.18 (I13)
unnamed: C34.1, RV26.2, U3.17 (I14)
unnamed: C36.1, RV25.2, U3.16 (I15)
unnamed: D1.2 (A), R3.2
unnamed: D2.2 (A), R4.2
unnamed: D3.2 (A), R6.2
unnamed: D4.2 (A), R8.2
unnamed: D5.1 (K), R7.1, U4.2 (A)
unnamed: J1.R, J2.2, J5.R
unnamed: J1.S, J2.1, J5.S
unnamed: J1.T, J2.3, J5.T
unnamed: JP1.2 (C), U5.1
unnamed: R10.2, U5.4
unnamed: R12.2, U1.19 (27_A13_SCK1)
unnamed: U5.2, U5.3

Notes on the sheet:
Bourns PTV09A Series / Alpha RV09 Series PTV09A-4025U-103 15mm 10K
6N137 has open collector/drain
Neutrik NMJ6HFD2
LEDs 3mm through-hole, low current type 1-2mA
Bourns PEC12 Series 15mm Switched 24ppr
Used as Analogue GND
Texas Instruments CD4067BM96 SOIC-24_7.5x15.4x1.27P
PCB mount DIN 180deg 5 pin socket
tinyurl.com/MIDI-DIN-Spec
(Not VUSB on 49 (removed) which is an 'inside' pin)
Unused SPI
Everlite Elec 6N137S SMD-8_6.6x9.8x2.54P
All +3V3 All caps are 0.1uF
Unused SPI (10k pull-up)
Optional MIDI TRS jacks instead of the 5 pin DIN. Follows MIDI Assoc spec: tinyurl.com/MIDI-TRS-Spec
ON Semicon 1N4148WS SOD-323
Choose soft or hard MIDI thru
All resistors and capacitors 0805
12mm x 12mm x 7.3mm type
The Audio Board is mounted on the Teensy. Unsed SPI means that the SD card and optional memory chip aren't used and these pins are therefore, available. See www.pjrc.com/store/teensy3_audio.html
To pads beneath T4.1 USB
0.96" IPS Colour Display 160 x 80 SPI interface
Choose one jack or other, both share same PCB space
Unused CS on SD (10k pull-up) Used for display backlight
To pads beneath Audio Board

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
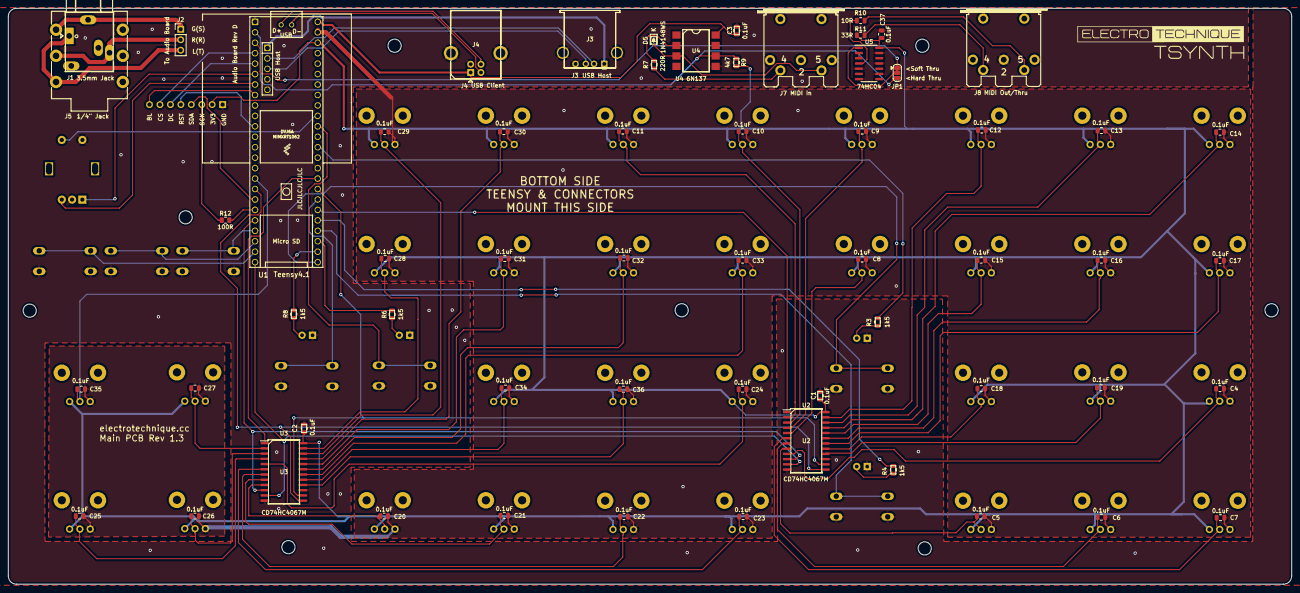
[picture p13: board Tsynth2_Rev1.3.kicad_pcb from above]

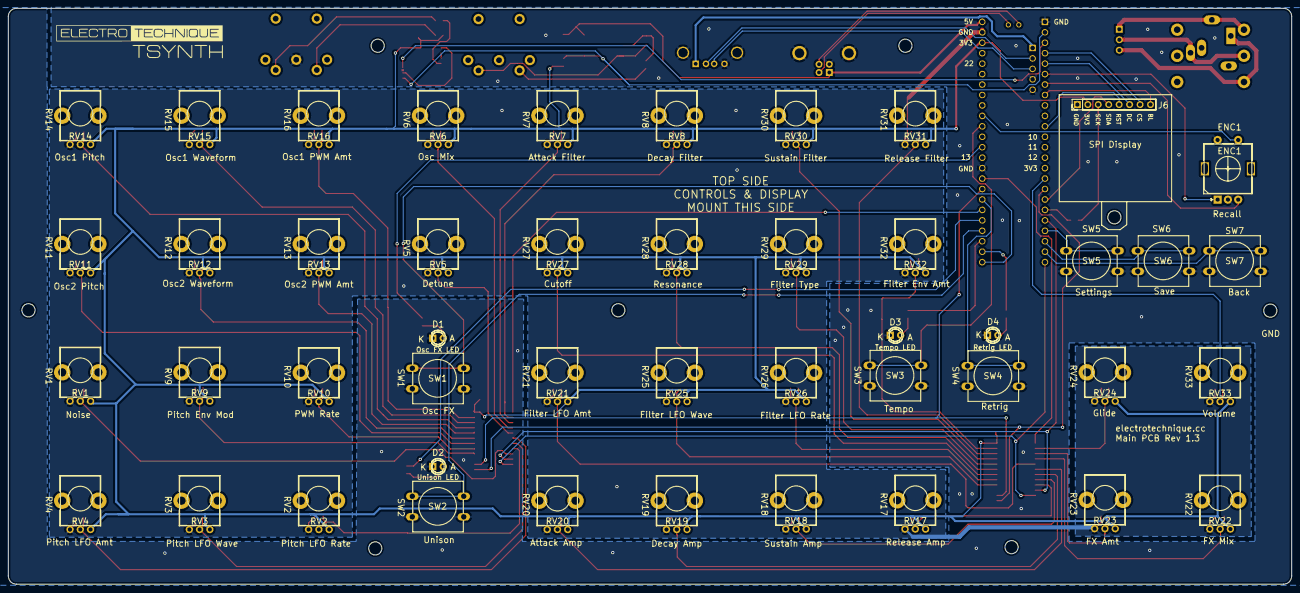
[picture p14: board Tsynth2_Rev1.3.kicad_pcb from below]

Board: 2 copper layers, 312.0 x 140.0 mm, 108 parts (47 on the bottom side), 86 nets.

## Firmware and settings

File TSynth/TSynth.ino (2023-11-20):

/*
   MIT License

  Copyright (c) 2020-21 ElectroTechnique

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
  ElectroTechnique TSynth - Firmware Rev 2.33
  TEENSY 4.1 - 12 VOICES

  Arduino IDE Tools Settings:
    Board: "Teensy4.1"
    USB Type: "Serial + MIDI + Audio"
    CPU Speed: "600MHz"
    Optimize: "Faster"

  Performance Tests   Max CPU  Mem
  600MHz Faster        80+     59

  Includes code by:
    Dave Benn - Handling MUXs, a few other bits and original inspiration  https://www.notesandvolts.com/2019/01/teensy-synth-part-10-hardware.html
    Alexander Davis / Vince R. Pearson - Stereo ensemble chorus effect https://github.com/quarterturn/teensy3-ensemble-chorus
    Will Winder - Major refactoring and monophonic mode
    Vince R. Pearson - Exponential envelopes & glide
    Github members fab672000 & CDW2000 - General improvements to code
    Mark Tillotson - Special thanks for band-limiting the waveforms in the Audio Library

  Additional libraries:
    Agileware CircularBuffer, Adafruit_GFX (available in Arduino libraries manager)
*/
#include <vector>
#include "Audio.h" //Using local version to override Teensyduino version
#include <Wire.h>
#include <SPI.h>
#include <SD.h>
#include <MIDI.h>
#include <USBHost_t36.h>
#include <TeensyThreads.h>
#include "MidiCC.h"
#include "SettingsService.h"
#include "AudioPatching.h"
#include "Constants.h"
#include "Parameters.h"
#include "PatchMgr.h"
#include "HWControls.h"
#include "EepromMgr.h"
#include "Detune.h"
#include "utils.h"
#include "Voice.h"
#include "VoiceGroup.h"

#define PARAMETER 0     // The main page for displaying the current patch and control (parameter) changes
#define RECALL 1        // Patches list
#define SAVE 2          // Save patch page
#define REINITIALISE 3  // Reinitialise message
#define PATCH 4         // Show current patch bypassing PARAMETER
#define PATCHNAMING 5   // Patch naming page
#define DELETE 6        // Delete patch page
#define DELETEMSG 7     // Delete patch message page
#define SETTINGS 8      // Settings page
#define SETTINGSVALUE 9 // Settings page

uint32_t state = PARAMETER;

// Initialize the audio configuration.
Global global{VOICEMIXERLEVEL};
// VoiceGroup voices1{global.SharedAudio[0]};
std::vector<VoiceGroup *> groupvec;
uint8_t activeGroupIndex = 0;
uint8_t loopCount = 0;

boolean usbHostPluggedIn = false;
elapsedMillis usb_host_wait_timer;

#include "ST7735Display.h"

// USB HOST MIDI Class Compliant
USBHost myusb;
USBHub hub1(myusb);
USBHub hub2(myusb);
MIDIDevice midi1(myusb);
// MIDIDevice_BigBuffer midi1(myusb); // Try this if your MIDI Compliant controller has problems

// MIDI 5 Pin DIN
MIDI_CREATE_INSTANCE(HardwareSerial, Serial1, MIDI);

void changeMIDIThruMode()
{
  MIDI.turnThruOn(MIDIThru);
}

#include "Settings.h"

boolean cardStatus = false;
boolean firstPatchLoaded = false;

float previousMillis = millis(); // For MIDI Clk Sync

uint8_t count = 0;            // For MIDI Clk Sync
uint16_t patchNo = 1;         // Current patch no
long earliestTime = millis(); // For voice allocation - initialise to now

FLASHMEM void setup()
{
  // Initialize the voice groups.
  uint8_t total = 0;
  while (total < global.maxVoices())
  {
    VoiceGroup *currentGroup = new VoiceGroup{global.SharedAudio[groupvec.size()]};

    for (uint8_t i = 0; total < global.maxVoices() && i < global.maxVoicesPerGroup(); i++)
    {
      Voice *v = new Voice(global.Oscillators[i], i);
      currentGroup->add(v);
      total++;
    }

    groupvec.push_back(currentGroup);
  }

  setupDisplay();
  setUpSettings();
  setupHardware();

  AudioMemory(60);
  global.sgtl5000_1.enable();
  global.sgtl5000_1.volume(0.5 * SGTL_MAXVOLUME);
  global.sgtl5000_1.dacVolumeRamp();
  global.sgtl5000_1.muteHeadphone();
  global.sgtl5000_1.muteLineout();
  global.sgtl5000_1.audioPostProcessorEnable();
  global.sgtl5000_1.enhanceBass(0.85, 0.87, 0, 4); // Normal level, bass level, HPF bypass (1 - on), bass cutoff freq
  global.sgtl5000_1.enhanceBassDisable();          // Turned on from EEPROM

  cardStatus = SD.begin(BUILTIN_SDCARD);
  if (cardStatus)
  {
    Serial.println(F("SD card is connected"));
    // Get patch numbers and names from SD card
    loadPatches();
    if (patches.size() == 0)
    {
      // save an initialised patch to SD card
      savePatch("1", INITPATCH);
      loadPatches();
    }
  }
  else
  {
    Serial.println(F("SD card is not connected or unusable"));
    reinitialiseToPanel();
    showPatchPage(F("No SD"), F("conn'd / usable"));
  }

  // Read MIDI Channel from EEPROM
  midiChannel = getMIDIChannel();
  Serial.println(F("MIDI In Ch:") + String(midiChannel) + F(" (0 is Omni On)"));

  // USB HOST MIDI Class Compliant
  delay(200); // Wait to turn on USB Host
  myusb.begin();
  midi1.setHandleControlChange(usbHostControlChange);
  midi1.setHandleNoteOff(myNoteOff);
  midi1.setHandleNoteOn(myNoteOn);
  midi1.setHandlePitchChange(myPitchBend);
  midi1.setHandleProgramChange(myProgramChange);
  midi1.setHandleClock(myMIDIClock);
  midi1.setHandleStart(myMIDIClockStart);
  midi1.setHandleStop(myMIDIClockStop);
  Serial.println(F("USB HOST MIDI Class Compliant Listening"));

  // USB Client MIDI
  usbMIDI.setHandleControlChange(myControlChange);
  usbMIDI.setHandleNoteOff(myNoteOff);
  usbMIDI.setHandleNoteOn(myNoteOn);
  usbMIDI.setHandlePitchChange(myPitchBend);
  usbMIDI.setHandleProgramChange(myProgramChange);
  usbMIDI.setHandleClock(myMIDIClock);
  usbMIDI.setHandleStart(myMIDIClockStart);
  usbMIDI.setHandleStop(myMIDIClockStop);
  Serial.println(F("USB Client MIDI Listening"));

  // MIDI 5 Pin DIN
  MIDI.begin();
  MIDI.setHandleNoteOn(myNoteOn);
  MIDI.setHandleNoteOff(myNoteOff);
  MIDI.setHandlePitchBend(myPitchBend);
  MIDI.setHandleControlChange(myControlChange);
  MIDI.setHandleProgramChange(myProgramChange);
  MIDI.setHandleClock(myMIDIClock);
  MIDI.setHandleStart(myMIDIClockStart);
  MIDI.setHandleStop(myMIDIClockStop);
  Serial.println(F("MIDI In DIN Listening"));

  volumePrevious = RE_READ; // Force volume control to be read and set to current

  // Read Pitch Bend Range from EEPROM
  pitchBendRange = getPitchBendRange();
  // Read Mod Wheel Depth from EEPROM
  modWheelDepth = getModWheelDepth();
  // Read MIDI Out Channel from EEPROM
  midiOutCh = getMIDIOutCh();
  // Read MIDI Thru mode from EEPROM
  MIDIThru = getMidiThru();
  changeMIDIThruMode();
  // Read Encoder Direction from EEPROM
  encCW = getEncoderDir();
  // Read Pick-up enable from EEPROM - experimental feature
  pickUp = getPickupEnable();
  // Read bass enhance enable from EEPROM
  if (getBassEnhanceEnable())
    global.sgtl5000_1.enhanceBassEnable();
  // Read oscilloscope enable from EEPROM
  enableScope(getScopeEnable());
  // Read VU enable from EEPROM
  vuMeter = getVUEnable();
  // Read Filter and Amp Envelope shapes
  reloadFiltEnv();
  reloadAmpEnv();
  reloadGlideShape();
}

void myNoteOn(byte channel, byte note, byte velocity)
{
  // Check for out of range notes
  if (note + groupvec[activeGroupIndex]->params().oscPitchA < 0 || note + groupvec[activeGroupIndex]->params().oscPitchA > 127 || note + groupvec[activeGroupIndex]->params().oscPitchB < 0 || note + groupvec[activeGroupIndex]->params().oscPitchB > 127)
    return;

  groupvec[activeGroupIndex]->noteOn(note, velocity);
}

void myNoteOff(byte channel, byte note, byte velocity)
{
  groupvec[activeGroupIndex]->noteOff(note);
}

int getLFOWaveform(int value)
{
  if (value >= 0 && value < 8)
  {
    return WAVEFORM_SINE;
  }
  else if (value >= 8 && value < 30)
  {
    return WAVEFORM_TRIANGLE;
  }
  else if (value >= 30 && value < 63)
  {
    return WAVEFORM_SAWTOOTH_REVERSE;
  }
  else if (value >= 63 && value < 92)
  {
    return WAVEFORM_SAWTOOTH;
  }
  else if (value >= 92 && value < 111)
  {
    return WAVEFORM_SQUARE;
  }
  else
  {
    return WAVEFORM_SAMPLE_HOLD;
  }
}

FLASHMEM String getWaveformStr(int value)
{
  switch (value)
  {
  case WAVEFORM_SILENT:
    return F("Off");
  case WAVEFORM_SAMPLE_HOLD:
    return F("Sample & Hold");
  case WAVEFORM_SINE:
    return F("Sine");
  case WAVEFORM_BANDLIMIT_SQUARE:
  case WAVEFORM_SQUARE:
    return F("Square");
  case WAVEFORM_TRIANGLE:
    return F("Triangle");
  case WAVEFORM_BANDLIMIT_SAWTOOTH:
  case WAVEFORM_SAWTOOTH:
    return F("Sawtooth");
  case WAVEFORM_SAWTOOTH_REVERSE:
    return F("Ramp");
  case WAVEFORM_BANDLIMIT_PULSE:
    return F("Var. Pulse");
  case WAVEFORM_TRIANGLE_VARIABLE:
    return F("Var. Triangle");
  case WAVEFORM_PARABOLIC:
    return F("Parabolic");
  case WAVEFORM_HARMONIC:
    return F("Harmonic");
  default:
    return F("ERR_WAVE");
  }
}

FLASHMEM int getWaveformA(int value)
{
  if (value >= 0 && value < 7)
  {
    // This will turn the osc off
    return WAVEFORM_SILENT;
  }
  else if (value >= 7 && value < 23)
  {
    return WAVEFORM_TRIANGLE;
  }
  else if (value >= 23 && value < 40)
  {
    return WAVEFORM_BANDLIMIT_SQUARE;
  }
  else if (value >= 40 && value < 60)
  {
    return WAVEFORM_BANDLIMIT_SAWTOOTH;
  }
  else if (value >= 60 && value < 80)
  {
    return WAVEFORM_BANDLIMIT_PULSE;
  }
  else if (value >= 80 && value < 100)
  {
    return WAVEFORM_TRIANGLE_VARIABLE;
  }
  else if (value >= 100 && value < 120)
  {
    return WAVEFORM_PARABOLIC;
  }
  else
  {
    return WAVEFORM_HARMONIC;
  }
}

FLASHMEM int getWaveformB(int value)
{
  if (value >= 0 && value < 7)
  {
    // This will turn the osc off
    return WAVEFORM_SILENT;
  }
  else if (value >= 7 && value < 23)
  {
    return WAVEFORM_SAMPLE_HOLD;
  }
  else if (value >= 23 && value < 40)
  {
    return WAVEFORM_BANDLIMIT_SQUARE;
  }
  else if (value >= 40 && value < 60)
  {
    return WAVEFORM_BANDLIMIT_SAWTOOTH;
  }
  else if (value >= 60 && value < 80)
  {
    return WAVEFORM_BANDLIMIT_PULSE;
  }
  else if (value >= 80 && value < 100)
  {
    return WAVEFORM_TRIANGLE_VARIABLE;
  }
  else if (value >= 100 && value < 120)
  {
    return WAVEFORM_PARABOLIC;
  }
  else
  {
    return WAVEFORM_HARMONIC;
  }
}

FLASHMEM void updateUnison(uint8_t unison)
{
  groupvec[activeGroupIndex]->setUnisonMode(unison);

  if (unison == 0)
  {
    showCurrentParameterPage(F("Unison"), F("Off"));
    pinMode(UNISON_LED, OUTPUT);
    digitalWriteFast(UNISON_LED, LOW); // LED off
  }
  else if (unison == 1)
  {
    showCurrentParameterPage(F("Dyn. Unison"), F("On"));
    pinMode(UNISON_LED, OUTPUT);
    digitalWriteFast(UNISON_LED, HIGH); // LED on
  }
  else
  {
    showCurrentParameterPage(F("Chd. Unison"), F("On"));
    analogWriteFrequency(UNISON_LED, 1); // This is to make the LED flash using PWM rather than some thread
    analogWrite(UNISON_LED, 127);
  }
}

FLASHMEM void updateVolume(float vol)
{
  global.sgtl5000_1.volume(vol * SGTL_MAXVOLUME);
  showCurrentParameterPage(F("Volume"), vol);
}

FLASHMEM void updateGlide(float glideSpeed)
{
  groupvec[activeGroupIndex]->params().glideSpeed = glideSpeed;
  showCurrentParameterPage(F("Glide"), milliToString(glideSpeed * GLIDEFACTOR));
}

FLASHMEM void updateWaveformA(uint32_t waveform)
{
  groupvec[activeGroupIndex]->setWaveformA(waveform);
  showCurrentParameterPage(F("1. Waveform"), getWaveformStr(waveform));
}

FLASHMEM void updateWaveformB(uint32_t waveform)
{
  groupvec[activeGroupIndex]->setWaveformB(waveform);
  showCurrentParameterPage(F("2. Waveform"), getWaveformStr(waveform));
}

FLASHMEM void updatePitchA(int pitch)
{
  groupvec[activeGroupIndex]->params().oscPitchA = pitch;
  groupvec[activeGroupIndex]->updateVoices();
  showCurrentParameterPage("1. Semitones", (pitch > 0 ? "+" : "") + String(pitch));
}

FLASHMEM void updatePitchB(int pitch)
{
  groupvec[activeGroupIndex]->params().oscPitchB = pitch;
  groupvec[activeGroupIndex]->updateVoices();
  showCurrentParameterPage(F("2. Semitones"), (pitch > 0 ? "+" : "") + String(pitch));
}

FLASHMEM void updateDetune(float detune, uint32_t chordDetune)
{
  groupvec[activeGroupIndex]->params().detune = detune;
  groupvec[activeGroupIndex]->params().chordDetune = chordDetune;
  groupvec[activeGroupIndex]->updateVoices();

  if (groupvec[activeGroupIndex]->params().unisonMode == 2)
  {
    showCurrentParameterPage(F("Chord"), CDT_STR[chordDetune]);
  }
  else
  {
    showCurrentParameterPage(F("Detune"), String((1 - detune) * 100) + F(" %"));
  }
}

FLASHMEM void updatePWMSource(uint8_t source)
{
  groupvec[activeGroupIndex]->setPWMSource(source);

  if (source == PWMSOURCELFO)
  {
    showCurrentParameterPage(F("PWM Source"), F("LFO")); // Only shown when updated via MIDI
  }
  else
  {
    showCurrentParameterPage(F("PWM Source"), F("Filter Env"));
  }
}

FLASHMEM void updatePWMRate(float value)
{
  groupvec[activeGroupIndex]->setPwmRate(value);

  if (value == PWMRATE_PW_MODE)
  {
    // Set to fixed PW mode
    showCurrentParameterPage(F("PW Mode"), F("On"));
  }
  else if (value == PWMRATE_SOURCE_FILTER_ENV)
  {
    // Set to Filter Env Mod source
    showCurrentParameterPage(F("PWM Source"), F("Filter Env"));
  }
  else
  {
    showCurrentParameterPage(F("PWM Rate"), String(2 * value) + F(" Hz")); // PWM goes through mid to maximum, sounding effectively twice as fast
  }
}

FLASHMEM void updatePWMAmount(float value)
{
  // MIDI only - sets both osc PWM
  groupvec[activeGroupIndex]->overridePwmAmount(value);
  showCurrentParameterPage(F("PWM Amt"), String(value) + F(" : ") + String(value));
}

FLASHMEM void updatePWA(float valuePwA, float valuePwmAmtA)
{
  groupvec[activeGroupIndex]->setPWA(valuePwA, valuePwmAmtA);

  if (groupvec[activeGroupIndex]->getPwmRate() == PWMRATE_PW_MODE)
  {
    if (groupvec[activeGroupIndex]->getWaveformA() == WAVEFORM_TRIANGLE_VARIABLE)
    {
      showCurrentParameterPage(F("1. PW Amt"), VAR_TRI, groupvec[activeGroupIndex]->getPwA());
    }
    else
    {
      showCurrentParameterPage(F("1. PW Amt"), PULSE, groupvec[activeGroupIndex]->getPwA());
    }
  }
  else
  {
    if (groupvec[activeGroupIndex]->getPwmSource() == PWMSOURCELFO)
    {
      // PW alters PWM LFO amount for waveform A
      showCurrentParameterPage(F("1. PWM Amt"), F("LFO ") + String(groupvec[activeGroupIndex]->getPwmAmtA()));
    }
    else
    {
      // PW alters PWM Filter Env amount for waveform A
      showCurrentParameterPage(F("1. PWM Amt"), F("F. Env ") + String(groupvec[activeGroupIndex]->getPwmAmtA()));
    }
  }
}

FLASHMEM void updatePWB(float valuePwB, float valuePwmAmtB)
{
  groupvec[activeGroupIndex]->setPWB(valuePwB, valuePwmAmtB);

  if (groupvec[activeGroupIndex]->getPwmRate() == PWMRATE_PW_MODE)
  {
    if (groupvec[activeGroupIndex]->getWaveformB() == WAVEFORM_TRIANGLE_VARIABLE)
    {
      showCurrentParameterPage(F("2. PW Amt"), VAR_TRI, groupvec[activeGroupIndex]->getPwB());
    }
    else
    {
      showCurrentParameterPage(F("2. PW Amt"), PULSE, groupvec[activeGroupIndex]->getPwB());
    }
  }
  else
  {
    if (groupvec[activeGroupIndex]->getPwmSource() == PWMSOURCELFO)
    {
      // PW alters PWM LFO amount for waveform B
      showCurrentParameterPage(F("2. PWM Amt"), F("LFO ") + String(groupvec[activeGroupIndex]->getPwmAmtB()));
    }
    else
    {
      // PW alters PWM Filter Env amount for waveform B
      showCurrentParameterPage(F("2. PWM Amt"), F("F. Env ") + String(groupvec[activeGroupIndex]->getPwmAmtB()));
    }
  }
}

FLASHMEM void updateOscLevelA(float value)
{
  groupvec[activeGroupIndex]->setOscLevelA(value);

  switch (groupvec[activeGroupIndex]->getOscFX())
  {
  case 1: // XOR
    showCurrentParameterPage(F("Osc Mix 1:2"), F("   ") + String(groupvec[activeGroupIndex]->getOscLevelA()) + F(" : ") + String(groupvec[activeGroupIndex]->getOscLevelB()));
    break;
  case 2: // XMod
    // osc A sounds with increasing osc B mod
    if (groupvec[activeGroupIndex]->getOscLevelA() == 1.0f && groupvec[activeGroupIndex]->getOscLevelB() <= 1.0f)
    {
      showCurrentParameterPage(F("XMod Osc 1"), F("Osc 2: ") + String(1 - groupvec[activeGroupIndex]->getOscLevelB()));
    }
    break;
  case 0: // None
    showCurrentParameterPage(F("Osc Mix 1:2"), F("   ") + String(groupvec[activeGroupIndex]->getOscLevelA()) + F(" : ") + String(groupvec[activeGroupIndex]->getOscLevelB()));
    break;
  }
}

FLASHMEM void updateOscLevelB(float value)
{
  groupvec[activeGroupIndex]->setOscLevelB(value);

  switch (groupvec[activeGroupIndex]->getOscFX())
  {
  case 1: // XOR
    showCurrentParameterPage(F("Osc Mix 1:2"), F("   ") + String(groupvec[activeGroupIndex]->getOscLevelA()) + F(" : ") + String(groupvec[activeGroupIndex]->getOscLevelB()));
    break;
  case 2: // XMod
    // osc B sounds with increasing osc A mod
    if (groupvec[activeGroupIndex]->getOscLevelB() == 1.0f && groupvec[activeGroupIndex]->getOscLevelA() < 1.0f)
    {
      showCurrentParameterPage(F("XMod Osc 2"), F("Osc 1: ") + String(1 - groupvec[activeGroupIndex]->getOscLevelA()));
    }
    break;
  case 0: // None
    showCurrentParameterPage(F("Osc Mix 1:2"), F("   ") + String(groupvec[activeGroupIndex]->getOscLevelA()) + F(" : ") + String(groupvec[activeGroupIndex]->getOscLevelB()));
    break;
  }
}

FLASHMEM void updateNoiseLevel(float value)
{
  float pink = 0.0;
  float white = 0.0;
  if (value > 0)
  {
    pink = value;
  }
  else if (value < 0)
  {
    white = abs(value);
  }

  groupvec[activeGroupIndex]->setPinkNoiseLevel(pink);
  groupvec[activeGroupIndex]->setWhiteNoiseLevel(white);

  if (value > 0)
  {
    showCurrentParameterPage(F("Noise Level"), F("Pink ") + String(value));
  }
  else if (value < 0)
  {
    showCurrentParameterPage(F("Noise Level"), F("White ") + String(abs(value)));
  }
  else
  {
    showCurrentParameterPage(F("Noise Level"), F("Off"));
  }
}

FLASHMEM void updateFilterFreq(float value)
{
  groupvec[activeGroupIndex]->setCutoff(value);
  showCurrentParameterPage(F("Cutoff"), String(int(value)) + F(" Hz"));
}

FLASHMEM void updateFilterRes(float value)
{
  groupvec[activeGroupIndex]->setResonance(value);
  showCurrentParameterPage(F("Resonance"), value);
}

FLASHMEM void updateFilterMixer(float value)
{
  groupvec[activeGroupIndex]->setFilterMixer(value);

  String filterStr;
  if (value == BANDPASS)
  {
    filterStr = F("Band Pass");
  }
  else
  {
    // LP-HP mix mode - a notch filter
    if (value == LOWPASS)
    {
      filterStr = F("Low Pass");
    }
    else if (value == HIGHPASS)
    {
      filterStr = F("High Pass");
    }
    else
    {
      filterStr = F("LP ") + String(100 - int(100 * value)) + F(" - ") + String(int(100 * value)) + F(" HP");
    }
  }

  showCurrentParameterPage(F("Filter Type"), filterStr);
}

FLASHMEM void updateFilterEnv(float value)
{
  groupvec[activeGroupIndex]->setFilterEnvelope(value);
  showCurrentParameterPage(F("Filter Env."), String(value));
}

FLASHMEM void updatePitchEnv(float value)
{
  groupvec[activeGroupIndex]->setPitchEnvelope(value);
  showCurrentParameterPage(F("Pitch Env Amt"), String(value));
}

FLASHMEM void updateKeyTracking(float value)
{
  groupvec[activeGroupIndex]->setKeytracking(value);
  showCurrentParameterPage(F("Key Tracking"), String(value));
}

FLASHMEM void updatePitchLFOAmt(float value)
{
  groupvec[activeGroupIndex]->setPitchLfoAmount(value);
  char buf[10];
  showCurrentParameterPage(F("LFO Amount"), dtostrf(value, 4, 3, buf));
}

FLASHMEM void updateModWheel(float value)
{
  groupvec[activeGroupIndex]->setModWhAmount(value);
}

FLASHMEM void updatePitchLFORate(float value)
{
  groupvec[activeGroupIndex]->setPitchLfoRate(value);
  showCurrentParameterPage(F("LFO Rate"), String(value) + F(" Hz"));
}

FLASHMEM void updatePitchLFOWaveform(uint32_t waveform)
{
  groupvec[activeGroupIndex]->setPitchLfoWaveform(waveform);
  showCurrentParameterPage(F("Pitch LFO"), getWaveformStr(waveform));
}

// MIDI CC only
FLASHMEM void updatePitchLFOMidiClkSync(bool value)
{
  groupvec[activeGroupIndex]->setPitchLfoMidiClockSync(value);
  showCurrentParameterPage(F("P. LFO Sync"), value ? F("On") : F("Off"));
}

FLASHMEM void updateFilterLfoRate(float value, String timeDivStr)
{
  groupvec[activeGroupIndex]->setFilterLfoRate(value);

  if (timeDivStr.length() > 0)
  {
    showCurrentParameterPage(F("LFO Time Div"), timeDivStr);
  }
  else
  {
    showCurrentParameterPage(F("F. LFO Rate"), String(value) + F(" Hz"));
  }
}

FLASHMEM void updateFilterLfoAmt(float value)
{
  groupvec[activeGroupIndex]->setFilterLfoAmt(value);
  showCurrentParameterPage(F("F. LFO Amt"), String(value));
}

FLASHMEM void updateFilterLFOWaveform(uint32_t waveform)
{
  groupvec[activeGroupIndex]->setFilterLfoWaveform(waveform);
  showCurrentParameterPage(F("Filter LFO"), getWaveformStr(waveform));
}

FLASHMEM void updatePitchLFORetrig(bool value)
{
  groupvec[activeGroupIndex]->setPitchLfoRetrig(value);
  showCurrentParameterPage(F("P. LFO Retrig"), value ? F("On") : F("Off"));
}

FLASHMEM void updateFilterLFORetrig(bool value)
{
  groupvec[activeGroupIndex]->setFilterLfoRetrig(value);
  showCurrentParameterPage(F("F. LFO Retrig"), groupvec[activeGroupIndex]->getFilterLfoRetrig() ? F("On") : F("Off"));
  digitalWriteFast(RETRIG_LED, groupvec[activeGroupIndex]->getFilterLfoRetrig() ? HIGH : LOW); // LED
}

FLASHMEM void updateFilterLFOMidiClkSync(bool value)
{
  groupvec[activeGroupIndex]->setFilterLfoMidiClockSync(value);
  showCurrentParameterPage(F("Tempo Sync"), value ? F("On") : F("Off"));
  digitalWriteFast(TEMPO_LED, value ? HIGH : LOW); // LED
}

FLASHMEM void updateFilterAttack(float value)
{
  groupvec[activeGroupIndex]->setFilterAttack(value);
  showCurrentParameterPage(F("Filter Attack"), milliToString(value), FILTER_ENV);
}

FLASHMEM void updateFilterDecay(float value)
{
  groupvec[activeGroupIndex]->setFilterDecay(value);
  showCurrentParameterPage("Filter Decay", milliToString(value), FILTER_ENV);
}
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
void loop()
{
  // USB HOST MIDI Class Compliant
   myusb.Task();
  midi1.read(midiChannel);
  // USB Client MIDI
  usbMIDI.read(midiChannel);
  // MIDI 5 Pin DIN
  MIDI.read(midiChannel);
  if (loopCount++ > 9)
  {
    checkUSBHostStatus();
    checkMux();
    checkSwitches();
    checkEncoder();
    // CPUMonitor();
    loopCount = 0;
  }
}

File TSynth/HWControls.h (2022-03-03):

// This optional setting causes Encoder to use more optimized code,
// It must be defined before Encoder.h is included.
#define ENCODER_OPTIMIZE_INTERRUPTS
#include <Encoder.h>
#include "TButton.h"
#include <ADC.h>
#include <ADC_util.h>

ADC *adc = new ADC();

//Teensy 4.1 - Mux Pins
#define MUX_0 28
#define MUX_1 32
#define MUX_2 40
#define MUX_3 25
#define MUX1_S A14
#define MUX2_S A17
//Mux 1 Connections
#define MUX1_noiseLevel 0
#define MUX1_pitchLfoRate 1
#define MUX1_pitchLfoWaveform 2
#define MUX1_pitchLfoAmount 3
#define MUX1_detune 4
#define MUX1_oscMix 5
#define MUX1_filterAttack 6
#define MUX1_filterDecay 7
#define MUX1_pwmAmountA 8
#define MUX1_waveformA 9
#define MUX1_pitchA 10
#define MUX1_pwmAmountB 11
#define MUX1_waveformB 12
#define MUX1_pitchB 13
#define MUX1_pwmRate 14
#define MUX1_pitchEnv 15
//Mux 2 Connections
#define MUX2_release 0
#define MUX2_sustain 1
#define MUX2_decay 2
#define MUX2_attack 3
#define MUX2_filterLFOAmount 4
#define MUX2_FXMix 5
#define MUX2_FXAmount 6
#define MUX2_glide 7
#define MUX2_filterEnv 8
#define MUX2_filterRelease 9
#define MUX2_filterSustain 10
#define MUX2_filterType 11
#define MUX2_resonance 12
#define MUX2_cutoff 13
#define MUX2_filterLFORate 14
#define MUX2_filterLFOWaveform 15

//Teensy 4.1 Pins
#define OSC_FX_SW 33
#define FILTER_LFO_RETRIG_SW 39
#define UNISON_SW 36
#define TEMPO_SW 16
#define RECALL_SW 17
#define SAVE_SW 30
#define SETTINGS_SW 29
#define BACK_SW 31
#define VOLUME_POT A10

#define ENCODER_PINA 4
#define ENCODER_PINB 5

#define RETRIG_LED 34
#define TEMPO_LED 35
#define UNISON_LED 37
#define OSC_FX_LED 14

#define BACKLIGHT 6

#define MUXCHANNELS 16
#define QUANTISE_FACTOR 15// Sets a tolerance of noise on the ADC. 15 is 4 bits

#define DEBOUNCE 30

static byte muxInput = 0;
static uint16_t mux1ValuesPrev[MUXCHANNELS] = {};
static uint16_t mux2ValuesPrev[MUXCHANNELS] = {};

static uint16_t mux1Read = 0;
static uint16_t mux2Read = 0;
static int volumeRead = 0;
static int volumePrevious = 0;
static long encPrevious = 0;

//These are pushbuttons and require debouncing
TButton oscFXSwitch{OSC_FX_SW, LOW, HOLD_DURATION, DEBOUNCE, CLICK_DURATION};
TButton filterLFORetrigSwitch{FILTER_LFO_RETRIG_SW, LOW, HOLD_DURATION, DEBOUNCE, CLICK_DURATION};
TButton unisonSwitch{UNISON_SW, LOW, HOLD_DURATION, DEBOUNCE, CLICK_DURATION};
TButton tempoSwitch{TEMPO_SW, LOW, HOLD_DURATION, DEBOUNCE, CLICK_DURATION};
TButton recallButton{RECALL_SW, LOW, HOLD_DURATION, DEBOUNCE, CLICK_DURATION}; //On encoder
		
TButton saveButton{SAVE_SW, LOW, HOLD_DURATION, DEBOUNCE, CLICK_DURATION};
TButton settingsButton{SETTINGS_SW, LOW, HOLD_DURATION, DEBOUNCE, CLICK_DURATION};
TButton backButton{BACK_SW, LOW, HOLD_DURATION, DEBOUNCE, CLICK_DURATION};
Encoder encoder(ENCODER_PINB, ENCODER_PINA);//This often needs the pins swapping depending on the encoder

FLASHMEM void setupHardware() {
  //Volume Pot is on ADC0
  adc->adc0->setAveraging(16); // set number of averages 0, 4, 8, 16 or 32.
  adc->adc0->setResolution(12); // set bits of resolution  8, 10, 12 or 16 bits.
  adc->adc0->setConversionSpeed(ADC_CONVERSION_SPEED::VERY_LOW_SPEED); // change the conversion speed
  adc->adc0->setSamplingSpeed(ADC_SAMPLING_SPEED::MED_SPEED); // change the sampling speed

  //MUXs on ADC1
  adc->adc1->setAveraging(32); // set number of averages 0, 4, 8, 16 or 32.
  adc->adc1->setResolution(12); // set bits of resolution  8, 10, 12 or 16 bits.
  adc->adc1->setConversionSpeed(ADC_CONVERSION_SPEED::VERY_LOW_SPEED); // change the conversion speed
  adc->adc1->setSamplingSpeed(ADC_SAMPLING_SPEED::MED_SPEED); // change the sampling speed

  //Mux address pins
  pinMode(MUX_0, OUTPUT);
  pinMode(MUX_1, OUTPUT);
  pinMode(MUX_2, OUTPUT);
  pinMode(MUX_3, OUTPUT);

  //Mux ADC
  pinMode(MUX1_S, INPUT);
  pinMode(MUX2_S, INPUT);

  //Volume ADC
  pinMode(VOLUME_POT, INPUT);

  //Switches
  pinMode(OSC_FX_SW, INPUT_PULLUP);
  pinMode(FILTER_LFO_RETRIG_SW, INPUT_PULLUP);
  pinMode(UNISON_SW, INPUT_PULLUP);
  pinMode(TEMPO_SW, INPUT_PULLUP);
  pinMode(RECALL_SW, INPUT_PULLUP); //On encoder
  pinMode(SAVE_SW, INPUT_PULLUP);
  pinMode(SETTINGS_SW, INPUT_PULLUP);
  pinMode(BACK_SW, INPUT_PULLUP);

  //LEDs
  pinMode(RETRIG_LED, OUTPUT);
  pinMode(TEMPO_LED, OUTPUT);
  pinMode(UNISON_LED, OUTPUT);
  pinMode(OSC_FX_LED, OUTPUT);

  //Display backlight - Can be use to turn off or dim using PWM
  //pinMode(BACKLIGHT, OUTPUT);
}

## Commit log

2020-08-13 Add Velocity sensitivity
2020-08-13 Add velocity curves
2020-10-18 V2.01 - Mod wheel level adds to osc LFO level.
2020-11-15 V2.02 - Volume control, unison voice level and oscilloscope
    Volume control reverted back to controlling only headphone volume. USB digital and line out are at fixed volumes.
    Fix to code that sets the volume level due to velocity that made unison voices too loud.
    Some improvement to oscilloscope display.
2020-11-30 V2.03 - Fixed reintialise problem cause by RE_READ and QUANTISE_FACTOR
    [ST7735Display.h, TSynth.ino]
2021-01-12 V2.10 - Support for V1.3 PCB - soft MIDI thru, normalised unison volume level
2021-01-12 Support V1.3 PCB
2021-01-12 V2.10 - Support for V1.3 PCB - Soft MIDI thru/out, normalise unison volume levels
2021-03-06 Fix all compilation warnings, favor strict & cross-platform compatible casts.
    [EepromMgr.h, ST7735Display.h, TSynth.ino]
2021-03-06 Add Side Panel Column Stl and freecad models variants for plastic (larger) studs.
    [SidePanel_Column_LargerHole.FCStd, SidePanel_Column_LargerHole.stl]
2021-03-06 Clean up most of the x.y coordinates in the full design for better visual inspection in the Teensy Audio System Design Tool.
2021-04-06 V2.11 - Fixed minor bugs with parameter save and recall. Richer stereo chorus.
    [TSynth.ino]
2021-04-13 Update voice code to use Oscillator array.
    [ST7735Display.h, TSynth.ino]
2021-04-13 Use Oscillator array for other updates.
    [TSynth.ino]
2021-04-13 More usage of the oscillator array.
    [TSynth.ino]
2021-04-13 Additional fixes
    Added sixth phase tap
    Corrected lfoIndex 1-6 values to properly represent 6 phases at 60 degree intervals
    Corrected index cut/paste errors in waveform summation code
2021-04-14 - V2.14 - C&P error on updateAttack
    [TSynth.ino]
2021-04-17 Fix unison voice mixer level.
    [TSynth.ino]
2021-04-17 Use VoiceGroup.
    Move unison support into VoiceGroup.
    Fix the mixer level.
    Avoid range based for loop.
    Remove some unused stuff.
    [ST7735Display.h, TSynth.ino, VoiceGroup.h]
2021-04-18 Fix detune knob responsiveness during note.
    [ST7735Display.h, TSynth.ino, VoiceGroup.h]
2021-04-19 Fix problems with selecting settings and order of Monophonic mode to match indexes
    [TSynth.ino]
2021-04-19 Fix problems with selecting settings - end of value list
    [TSynth.ino]
2021-04-19 Move pitch envelope to voice group.
2021-04-19 Move PWM values into VoiceGroup
2021-04-20 Move resonance and filter mix to voice group.
2021-04-20 Move filter envelope to voice group.
2021-04-21 Move filter and amp ADSR to voice group.
2021-04-23 12 copies of filterLfo, move filterLfo into VoiceGroup.
2021-04-23 Split noise mixer per voice and move to voice group.
    [TSynth.ino, VoiceGroup.h]
2021-04-23 Copy of pwmLfo A and B per voice.
2021-04-25 Share a single noise mixer per voice group.
    [TSynth.ino, VoiceGroup.h]
2021-04-25 FilterLFO to dynamic audio connection.
2021-04-25 PWM LFO to dynamic connection in voice group, re-enable filter LFO.
2021-04-25 Dynamic patching with pitch filters, they still need to be moved into the VoiceGroup.
2021-04-25 Move pitch mixers into voice group.
2021-04-28 Fix amp env display paramtype (C&P error)
    [TSynth.ino]
2021-05-04 Fixed EEPROM store and recall for envelope types
    [EepromMgr.h, TSynth.ino]
2021-05-08 Changed from unsigned to signed integers in envelope filters, cleaned up code and comments
2021-05-10 Rearrange Settings menu items, bugfix to patchname in serial monitor
    [TSynth.ino]
2021-05-11 Revert "Update line endings and git line ending config."
    This reverts commit d68331e927c5a5f00579f1de91431351d1e772b4.
    [VoiceGroup.h]
2021-07-02 V2.31 - Fixed crash on unison with monophonic
    [Constants.cpp, TSynth.ino, VoiceGroup.h]
2022-01-05 V2.32 Fix PW amount for Osc 2 not updated from patch.
    [Constants.cpp, TSynth.ino]
2022-03-29 V2.33 - Oscilloscope and memory improvement, exp amp and filter env defaults
2022-03-29 V2.33 - Oscilloscope and memory improvements, exp ap and filter shape defaults.
2023-11-20 V2.35 - Improvements to handling of USB host plugging in, SPI speed dropped for lower noise, loop() improvement
    [Constants.cpp, ST7735Display.h, ST7735_t3.h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]
2023-12-25 V2.36 - Fix first held voice silenced - issue #136
    V2.36 - Fix first held voice silenced - issue #136
    [Constants.cpp, VoiceGroup.h]
2024-08-19 Fix issue with exponential envelope with non-zero delay
    In a corner case, where the state becomes STATE_IDLE EXACTLY at the end of an update(), AND noteOn() is called before the next update() occurs, AND delay_count is non-zero, AND the exponential envelope shape is in use, exp_count will have a stale value of 2^32-1 and the delay becomes about 9 days. Some code duplicated here - it might be possible to move it instead.
2026-11-11 Reduce MIDI note-on latency and jitter
    The display thread redrew continuously with the default 10ms TeensyThreads
    slice, holding off MIDI handling in the main loop by up to 10ms.
    - Throttle display refresh (30ms between frames) and cut its slice to 1ms
    - Drain up to 16 pending messages per MIDI input per loop
    - Apply note on/off atomically w.r.t. the audio update
    - Run MIDI clock handler from RAM instead of flash
    Claude-Session: https://claude.ai/code/session_0193ESmtgxXSjZk6qtqzW8rK
2026-11-11 Use DMA for display updates to restore refresh rate
    The blocking SPI transfer was spread across many 1ms thread slices,
    making the display laggy. DMA frees the CPU during the transfer; the
    frame delay now accounts for time spent rendering.
    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
2026-11-11 Prevent oscillator mix clipping that caused aliasing
    With Osc Mix centred both oscillators ran at gain 1.0; band-limited saws and
    squares peak at 0.88-0.95 FS, so the sum clipped the 16-bit mixer on ~10% of
    samples. Clipping adds non-band-limited edges (-17dB spurious content vs
    -70dB from the oscillator alone in host simulation).
    Scale Osc 1 + Osc 2 + XOR so the total gain is <= 1.0, and compensate the
    lost level (equal-power) at the voice mixer after the filter.
    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
2026-11-11 Rewrite ensemble: smooth LFO, cubic interpolation, fix tap/stereo phases
    - LFO is now computed per sample; previously the delay time stepped every
    16-150 samples, causing zipper sidebands (-14 to -25dB at 5-10kHz)
    - 4-point Hermite delay interpolation instead of linear (less HF warble)
    - Tap spacing restored to the intended 60 degrees; offsets were not scaled
    when the LFO table was enlarged 4x, leaving taps only 15 degrees apart
    - Right channel now uses a 90 degree LFO shift as intended; PHASE_90 was
    being added to the delay position, giving a fixed 3ms offset instead
    - Fixed point LFO from the sine table; drops the 24KB float LFO table and
    the integer rounding of the rate
    Host simu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
2026-11-12 Improve oscilloscope (ported from Momentum)
    - Schmitt trigger on rising zero crossings with sub-sample positioning, so
    the trace stands still
    - Timebase locked to the lowest held note's audible oscillator (two cycles)
    - Auto-scaled to the window instead of clipping above ~30% of full scale
    - Min/max per pixel column, or interpolated when under 2 samples per column
    - Taps the voices before the ensemble (DC-blocked SVF highpass output)
    - Audio interrupt only copies blocks into a 16KB ring buffer; triggering and
    drawing run in the display thread, just before each screen update
    Claude-Session: https://claude.ai/code/session_0193ESmtgxX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
2026-11-12 Fix filter overflow/clipping at high resonance, stolen-voice clicks, noise clipping
    Filter (Q up to 15 kept):
    - 4x internal headroom and halved output sums; loud input at Q >= 10 used to
    overflow and wrap around (full-scale jumps)
    - Soft limiter above 0.75 FS instead of hard clipping (linear below)
    - Input level lowered as resonance rises: -3dB at Q 5, ~-8dB at Q 15
    (RESONANCE_INPUT_COMP, 0 disables); unity at normal resonance
    - DC blocker keeps a linear, hard-limited output
    Voice stealing:
    - Prefer silent voices, then the oldest released voice, then the oldest held
    note (mono modes still reuse the same voice)
    - When a sounding voice is stolen, its new level/pitch/glide are applied on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
2026-11-12 Fix filter key tracking
    - Amount was applied twice (DC level and mixer gain), so Half gave 25%
    - Tracking now pivots around middle C (KEYTRACK_REF_NOTE) instead of always
    raising the cutoff, which brightened every note when key tracking was on
    - Scaled by the filter's octave range, so Full is exactly one octave of
    cutoff per octave played and Half is half that, at any cutoff setting
    (previously 9-64% for Full depending on the cutoff knob)
    - Held notes are updated when the cutoff or amount changes
    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
2026-11-12 Rewrite knob pick-up
    - Per-knob state instead of a global flag driven by the display timeout,
    which ungated every knob for 700ms after any change and re-armed knobs
    that had already picked up
    - Picks up when the knob reaches or crosses the stored value (any speed),
    instead of requiring a reading within +/-2 steps
    - The stored value is converted to the knob's range, as a band for stepped
    controls (waveforms, pitch), so every continuous panel knob is covered,
    not just 9
    - MIDI CCs are never gated; a MIDI change re-arms that knob
    - Re-armed on patch recall and when pick-up is enabled; reinitialise to panel
    releases all knobs
    - Fixes: MIDI cutoff window was a single point, out-of-ran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
2026-11-12 Fix freezes when recalling patches with a fast encoder turn
    - Encoder on the patch page now only selects and shows the patch; it is
    recalled once the encoder has been still for 150ms (PATCH_RECALL_DELAY_MS)
    instead of on every detent (SD read + every parameter each time)
    - Heap is now thread safe: newlib malloc has no locking in the Teensy core and
    both the display thread and the main loop allocate Strings; __malloc_lock
    stops thread switching for each allocation
    - Display state lock: the display thread renders while holding displayLock,
    and the main loop takes it when changing the display Strings or the patch
    list (show* functions, encoder, patch load/recall/save/delete)
    - Displ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
2026-11-13 Band-limited variable triangle
    The variable triangle was generated without band-limiting and aliased badly at
    high pitches, worst at extreme widths where it becomes saw-like (-16dB at
    3.5kHz, width 0.95).
    It is now the integral of a band-limited pulse (equivalent to BLAMP corner
    correction), reusing the existing band-limited step code, with a slow (~14Hz)
    pull towards the plain triangle to stop drift under PWM and pitch changes.
    Host simulation, aliasing at 3.5kHz: width 0.5 -31 -> -65dB, width 0.95
    -16 -> -53dB. Same waveform (phase shifted by W/2), level 0.92 for headroom.
    Applies to the voice oscillators (modulated waveform); the variable pulse is
    unchanged.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
2026-11-13 Fix DC offset of the band-limited pulse
    process_active_steps_pulse added BASE_AMPLITUDE/2 instead of BASE_AMPLITUDE
    when removing the duty cycle's DC, leaving a constant -0.18 FS offset on the
    variable pulse at every width. The DC went through the filter and amp
    envelope (thumps with fast envelopes) and used up headroom.
    Now uses the per-cycle sampled width, as the edges do. Host check: DC 0 at
    widths 3-97% and with PWM; AC level and aliasing unchanged.
    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
2026-11-13 Faster band-limited oscillators; fix variable triangle under modulation
    CPU: every band-limited edge costs ~33 step-table lookups. Previously each
    active edge was revisited every sample through a non-inlined lookup with a
    mirror branch (~38 instructions per lookup on the M7). A pulse has two edges
    per cycle, so two pulse oscillators on high notes could need more than the
    CPU has, starving the main loop and display (lock-up).
    - Step table unfolded once into a full table plus differences; a step's
    fraction never changes, so each lookup is two loads and one multiply
    - Each edge applies its level change at once and adds its residual to a
    small future buffer in one tight loop; the per-sample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
2026-11-13 Filter: TPT state variable filter (switchable back to Chamberlin)
    Replaces the 2x oversampled Chamberlin SVF core with a TPT (zero-delay
    feedback, trapezoidal) SVF. Interface, LP/BP/HP outputs, Q range, resonance
    input compensation and soft limiting are unchanged.
    Host measurements, Q 10, modulated path:
    - Tuning: Chamberlin ran sharp with cutoff (+1.5% at 5kHz, +7.3% at 14kHz)
    and stopped at ~15kHz; TPT is within 0.1% from 1kHz to 17kHz
    - Resonance gain: Chamberlin fell from 5.2 to 3.8 towards the top; TPT 5.18
    at every cutoff
    - Stable at any cutoff/resonance (raising the Chamberlin clamp made it
    oscillate at low Q)
    - Cutoff/resonance changes are ramped across each block: block-rate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
2026-11-13 Fix display freezing under heavy MIDI traffic
    TeensyThreads' Mutex::lock() suspends a waiting thread and relies on unlock()
    to restart it. If the holder unlocks between the waiter's failed try_lock()
    and its suspend, the waiter is never restarted. Every CC updates the display
    text under displayLock, so with heavy CC traffic the display thread would
    eventually lose this race and stay suspended: display frozen, everything else
    working. The display lock now waits with try_lock() + yield() only.
    Also reports on Serial if a DMA screen update takes over 500ms, to tell a
    stalled transfer apart from other causes should a freeze remain.
    Claude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
2026-11-13 Panic: flush MIDI input and fully reset voice state
    - Panic (hold Back) now first reads and drops everything waiting in the USB
    host and USB device MIDI inputs (up to 50ms, in case the sender keeps
    going) and clears the DIN serial buffer without parsing it (so nothing is
    passed to MIDI thru), then silences all voices. Previously a backlog from a
    MIDI flood kept playing after Panic.
    - Envelope close() now clears the deferred-start flag; a voice that was being
    stolen when Panic was pressed could otherwise stay silent on its next note.
    - allNotesOff() also resets the active voice count and the mono note
    history (affects Panic, patch recall and MIDI All Notes Off); stale values
    ups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
2026-11-13 Display: single polled DMA transfer per frame (fixes DMA stall freeze)
    The driver's async update sends the frame as 40 sub-frames through two
    ping-pong buffers and counts completion interrupts. Each sub-frame takes
    ~340us at 24MHz SPI; if the DMA interrupt is delayed longer than that (heavy
    MIDI/USB load), two completions merge into one interrupt, the count slips,
    the channel is stopped on the wrong sub-frame and the final interrupt never
    comes. The update then stays active for ever and the display freezes
    (reported on Serial as 'DMA screen update stalled').
    New ST7735_t3::oneShotUpdate(): the whole frame (20480 pixels) in one DMA
    transfer from the frame buffer, flushed from the cache first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
2026-11-13 Prevent audio CPU overload hangs; suspend idle voices; cheaper variable triangle
    Playing 12 notes on preset 25 (Tremelo: variable triangle on both
    oscillators, an octave up, deep PWM) overran the audio CPU. The audio
    interrupt then runs back to back, the main loop and display get no time,
    note-offs are never read, so the load never drops: display frozen, last
    buffer replayed, reboot needed.
    - Overload guard (effect_cpuguard.h): runs at the end of each audio update;
    if the previous update used over 92% of the block time for 2 blocks, it
    silences one voice (oldest release tail, else oldest held note) and stops
    its oscillators. Reported on Serial as 'Audio CPU overload: a voice was
    dro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
2026-11-13 Remove unused second shared audio set; per-group CPU profile
    MAX_NO_TIMBER was 2, so Global built two PatchShared sets, but setup() only
    ever creates one voice group (SharedAudio[0]). The second set's LFOs, mixers,
    ensemble and DC filter were all connected and ran every block producing
    silence. Now 1.
    CPUMonitor() (uncomment the call in loop()) now prints once a second: total
    audio CPU and, by group, current/max % (oscillators, filters, envelopes, voice
    mixers, osc FX, DC, LFOs, shared mixers, ensemble, DC filter, noise, output).
    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
2026-11-13 Cut filter and ensemble CPU
    Profile on hardware (preset 25, ~10 notes): filters 18.7% (1.5% each),
    ensemble 7.4%.
    - TPT filter: cutoff coefficients (2^x, tan, division) every 4 samples,
    interpolated between, instead of every sample. Tuning, stability, response
    and smoothing unchanged in host tests; ordinary modulation differs from
    per-sample by -50dB.
    - Ensemble: LFOs (18 sine lookups per sample) every 8 samples with the tap
    delays interpolated; output matches the previous version to -60..-85dB.
    - Variable triangle drift correction stays per sample (doing it every 8
    samples was tried and added spurious tones).
    Claude-Session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
2026-11-13 Oscillators: generate whole blocks instead of a call per sample
    Hardware profile (preset 25, ~10 notes): oscillators 33% of audio CPU, about
    190 cycles per sample per oscillator. The variable triangle made two nested
    calls per sample (each saving 8-9 registers, plus float registers) and
    reloaded its state from memory every sample.
    - Variable triangle: block function with the state in locals; only the rare
    corners and the first-sample set-up make calls. Roughly half the
    instructions per sample.
    - Band-limited saw, square and pulse: block functions with the per-sample
    helpers inlined; only edge creation makes calls.
    - Output is sample-identical to the per-sample code (host checks with F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
2026-11-13 Cheaper voice mixers; no CPU spike or DC offset at variable triangle note start
    Hardware profile (preset 25, ~10 notes): total 62/64%, voice mixers 11%,
    oscillator max well above average.
    - AudioMixer4TS (mixer_ts.h) replaces AudioMixer4 throughout: skips
    zero-gain channels (AudioMixer4 multiplies them by zero) and only fetches
    the first used channel writable (a shared block such as an LFO is copied
    otherwise). Same saturating arithmetic: bit-identical in 200,000 random
    host cases, including silence when all present inputs are at zero gain.
    - Variable triangle start (waveform selected or silent voice resumed): the
    delay is filled directly instead of running a 32 sample pre-roll, w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
2026-11-13 Filter type mixer: constant level, mixed inside the filter, unity bandpass
    - LP-HP at constant level: LP = min(1, 2(1-m)), HP = min(1, 2m). The plain
    crossfade was 6dB down at the middle; the middle is now a full-level notch
    (LP + HP). Patches with in-between values get louder.
    - The mix is done inside the filter (new mix() mode, both cores): gains are
    smoothed per sample (no click switching types), the soft limiter acts on
    the mixed signal (in notch mode the opposite-phase LP/HP resonant peaks were
    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
2026-11-14 LFO smoothing, beat-locked MIDI clock sync, note retrigger option
    - Square, saw and sample & hold LFOs: 1ms one-pole smoothing of their jumps
    so they don't click on the filter, amplitude or pitch
    (AudioSynthWaveformTS::smoothing; sine/triangle unaffected).
    - MIDI clock sync: tempo measured per beat in microseconds (was ms) and
    synced LFOs kept in phase with the beat count since Start, by trimming the
    rate over the next beat (or setting the phase if far out). Previously only
    the rate was set, so a synced LFO kept an arbitrary offset and drifted.
    Host simulation: settles within ~2-5 degrees, including after a tempo
    change. Start now resets both synced LFOs (was the filter LFO onl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
2026-11-14 Audio block size 64 (PlatformIO build flag)
    Halves the audio block: notes start up to ~1.5ms after they arrive instead
    of ~2.9ms. TSynth's audio code supports any multiple of 16 (checked at
    compile time); the whole firmware builds and links with 64, and the
    oscillators' block code is sample-identical to per-sample at 64 in host
    tests. Remove the flag to go back to 128.
    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
2026-11-14 Firmware V3.00
    See https://github.com/Electrotechnique/TSynth-Teensy4.1/pull/143
2026-11-14 V3.01: display panel variant setting
    Some TSynth builds have a slightly different 0.96" 80x160 ST7735 panel:
    colours inverted, RGB/BGR swapped, mirrored or upside down, or shifted by a
    pixel. Previously fixed per user with a custom build (discussion #4 on
    electrotechnique.github.io).
    - Settings > Display: Standard, No invert, Blue tab (MV|RGB, row offset 0),
    Blue no inv, RGB order, No offset, Mirrored, Upside down. Each is shown
    live while scrolling; Settings saves it (EEPROM), Back reverts.
    - Hold Back at power on to reset to Standard, in case a setting makes the
    screen unreadable.
    - ST7735_t3::setPanelVariant() sets inversion, MADCTL and the drawing offset
    without re-initialising;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
2026-11-14 Oscilloscope only on the main patch page
    The trace was drawn over every page. It is now drawn only on the patch page
    (patch number, name and voice grid), not on parameter, settings, save,
    recall, naming or delete pages.
    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
2026-11-14 Unison: centre the detune spread on the played pitch (issue #125)
    In unison mode 1 every oscillator was set to pitch x (detune + (1-detune) x D)
    with D from 0 to 1 across the stack, so the whole spread sat between detune x
    pitch and the pitch: the stack was flat by half the detune (about 53 cents at
    full detune, 26 at half) and voice 1 osc A always took the full amount
    (107 cents flat at full detune).
    Now each oscillator is pitch x 2^((D - 0.5) x width), width = -log2(detune):
    the same overall spread, even in cents, centred on the pitch. Unison patches
    are now in tune at any detune setting (they sound higher than before by half
    the detune).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
